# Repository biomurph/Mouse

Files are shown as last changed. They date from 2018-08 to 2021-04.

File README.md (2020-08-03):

# Mouse
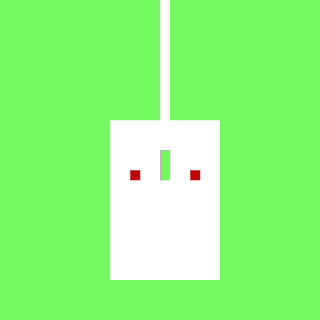
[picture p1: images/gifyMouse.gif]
MouseyMouse


### Repository for Open Source Mouse Firmware and Hardware
This repository holds the Arduino library, KiCAD PCB design files, gerber production files, BOM, and assembly instructions for the open-source computer mouse goodie bag item from the 2018 OSHWA Summit. The circuit design, PCB layout, and code were produced by Joel Murphy (aka biomurph | @SafeForRobots) in the Summer of 2018. The mouse wheel and wheel holder were designed in collaboration with Eugene Chang, and manufactured by [Tangible Creative](https://www.tangiblecreative.com). The production PCB boards were fabricated and stuffed by [Worthington Assembly](https://www.worthingtonassembly.com/). Thanks to Kelly Saxton for help in kitting and assembly instructions and the killer mouse morph gif! The microcontroller on board is a ATmega32u4 with Arduino Leonardo bootloader. This open-source mouse is a soldering kit, and comes pre-programmed with the example sketch from the Mousey Arduino library.

#### Assembly Instructions [Here](https://github.com/biomurph/Mouse/blob/master/AssemblyInstructions.md)
#### Library Functionality [Here](https://github.com/biomurph/Mouse/blob/master/LibraryFunctionality.md)
#### Hardware Design Files [Here](https://github.com/biomurph/Mouse/tree/master/Hardware)

## Anatomy of Mouse
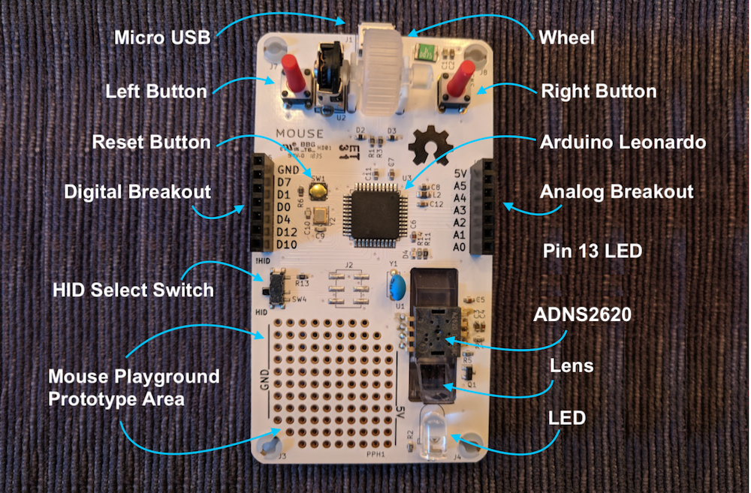
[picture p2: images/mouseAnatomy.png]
mouseProduction

### ADNS2620 !? That Went EOL Years Ago!
Yes, yes it did. Years ago, I tried to make a go of it in open-source hardware design, production and sales. I made something like [this](https://www.sparkfun.com/products/retired/10105) before SparkFun did, but it never got off the ground. I've been sitting on a small pile of components from those days, and this summer I decided that I have to chip away at that pile. So here you go. A fully functional computer mouse for you to hack and modify to your hearts delight. You're welcome!

If you are interested in modifying the design files to bring this project up to date, the one place that I have found that still sells these kinds of optical mouse sensors is a company called [PixArt](http://www.pixart.com.tw/index.asp) that has a variety of sensors to choose from. One of my goals is to do just that, so watch this repo if you want to be among the first to know when I have a working prototype.

### Installing The Firmware
Either download the ZIP of this repo or clone it. Then move or copy the file named `Mousey`
into your `Documents > Arduino > libraries` folder. Open or restart Arduino, Then
goto `File > Examples > Mousey > OpenMouse` to find the sketch that runs on OpenMouse.

# Use Your Mouse
This open-source computer mouse is built around an ATmega32u4 with the Arduino Leonardo bootloader. It has already been programmed with the example sketch from the Mousey library. There are two modes of operation HID and Not-HID. Modes are selected using the slide switch on the left side of the mouse.

## HID Mode
When the slide switch is on the side closest to the pad per hole prototyping area (aka DOWN), the mouse is in HID mode. When plugged into a micro USB cable, the mouse will read the sensors (wheel, buttons, optical sensor), and function just like a mouse attached to your computer!

## Not-HID Mode
When the slide switch is on the side closest to the 7 pin female header (aka UP), the mouse is in the Not-HID mode. When plugged into a micro USB cable, the mouse will read the sensors (wheel, buttons, optical sensor) and send the data it gets over serial at 115200 baud. You can open any serial terminal to view the data from the mouse.

## Troubleshooting
The mice were packaged with the HID select switch in the HID position. If you plug your mouse in to a computer and it doesn't work like a mouse should, then check to make sure that the HID switch is in HID mode. The small tact switch labeled `SW1` is the reset button for the Leonardo. You can switch modes on the fly, and press this reset button to change modes without unplugging your mouse. If all else fails, re-program the mouse with the OpenMouse.ino code from the example in the Mousey Library.

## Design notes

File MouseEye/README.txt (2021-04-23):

This Read Me is for Rachel's Electronics Mouse Eye Library. 
Written by Joel Murphy, Fall 2010
This Library offers full access to all the functionality 
of the Avago ADNS2620 at the heart of the Mouse Eye.
Use of the Library is discribed here.

First, connect the SDIO and SCK lines from the Mouse Eye to the arduino.
Any digital pins (2...13) will work for this connection.

To creat an instance of the Mouse Eye:
	MouseEye yourName(int SCK, ing SDIO);

This library sets up 2 variables and updates them through user functions. 

	.deltaX	char	holds change in X since the last time you ran .getMouse()
	.deltaY	char	holds change in Y since the last time you ran .getMouse()

>>>>>>   USER FUNCTIONS   <<<<<<<

	yourName.getMouse();

This function updates the variables .deltaX and .deltaY when you call it.
Variables will hold the change since the last time you called .getMouse().
Calling .getMouse() clears the X and Y registers.
Movement distance result is encoded as a 2's compliment number. The char type resolves this.

	yourName.Cofig_W(byte);

Writes a byte to the configuration register. Configuration register bits are:

	bit 7	Reset		0: no effect	1: reset the part
	bit 6	Power Down	0: normal operation	1: power down
	bit 5	Shutter Mode	0: Shutter Mode Off	1: Shutter Mode On
	bit 4...1	RESERVED
	bit 0	Forced Awake	0: Normal		1: Always Awake

Shutter Mode Off means the LED is always on even if no movement up to 1 second
Shutter Mode On means LED only on when electronic shutter is open

	byte yourName.Config_R();

Reads and returns the Configuration byte.

	byte yourName.Status();

Returns a byte that contains the product ID and mouse state data

	bits 7...5 		= Product ID  (010)
	bit 1		= Asleep/Awake  (0/1)

	byte yourName.Squal();

Returns a byte that reflects the surface quality of what the Mouse Eye sees.
This number x2 is the number of visible features on the surface. 
It is useful to read this register if you are finding the ideal distance between you mouse and the surface it is looking at.

	byte = yourName.Max_P();

Maximum gray scale value of a pixel in the current frame. Range = 0 to 63.

	byte = yourName.Min_P();

Minimum gray scale value of a pixel in the current frame. Range = 0 to 63.

	byte = yourName.Pixel_Sum();

Returns the average pixel gray scale value. Range from 0 to 63.

	word = yourName.Shutter();

Length of time the shutter is open in clock cycles. The sensor adjusts shutter to keep average and maximum pixel values within normal operating range. Value may change. Each time it changes, it changes by +- 1/16 of current value.

	void yourName.F_Period_W(byte);

Writes a byte to the Frame_Period register. Default value is 194. For dark surfaces, use a lower number.
see the datasheet for more details [http://www.rachelselectronics.com/Datasheets/ADNS-2620.pdf]

	byte yourName.F_Period_R();

Reads the value in the Frame_Period Register.

	your name.Pixel_Data_R();

Writes a byte to the Pixel_Data register to initiate frame capture and pixel dump. 
This command should be preceeded by a write of 1 to the Config register set the mouse in Awake mode.
Then there should be 324 successive reads from this register using yourName.Pixel_Data_R().
Here is an example use of the Pixel_Data commands:

	MoueseEye Mouse(int SCK, int SDIO);	// create instance of MouseEye

	byte P_data [324];			// byte array to hold grayscale data

	void setup(){
	Serial.begin (9600);
	}

	void loop(){
		//some event triggers a call to dumpPixels();
	}

	void dumpPixels(){
	    Mouse.Config_W(1);             	// force awake
	    Mouse.Pixel_Data();		// writes a byte to initiate pixel dump
	    for (int i=0; i<324; i++){
	      P_data[i] = Mouse.Pixel_Data_R();	//read grayscale data
	    }  
	    for (int i=0; i<324; i++){
	      Serial.print(P_data[i]); 		// display grayscale data
	    }
	    Mouse.Config_W(0);              	// undo force awake
	  }

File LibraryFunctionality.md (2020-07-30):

# Mouse Library Tools
Here is information about the user accessible functions in the Mousey library. The format of the data that is sent to the computer is determined by the HID select switch on the PCB. When the switch is set to `!HID` the mouse will send ASCII data to a serial terminal at 115200 baud whenever a mouse event occurs. When the switch is set to `HID` the mouse will use `Mouse.move`, `Mouse.pressed`, and `Mouse.released` to send mouse event data to the computer.

## update()
update checks all of the mouse inputs and sends relevant data to the computer if the buttons are pressed or released, if the mouse wheel moves, or if the mouse itself moves. It has proved to be important to have a delay in the loop when using the Mousey library, or else the mouse will overload the computer HID receiver and it will reduce performance. Experiment has shown that a delay of 5-10 milliseconds is good enough.

## checkEye()
Performs the necessary functions to update the `deltaX` and `deltaY` variables if they have changed, and sets the `mouseMoved` variable if that is so.

## checkWheel()
Checks to see if the `checkWheel` flag has been set by the interrupt service routine and sets the `mouseMoved` variable if that is so. The variable `deltaWheel` will hold the most recent wheel move data.

## checkButtons()
Reads the mouse buttons with a timed debounce routine and if there is a change in any of the button states, it sends data to the computer.

## Wheel Encoder
The mouse wheel encoder is of the digital switch type. There is an interrupt service routine called `encode()` which is triggered any time one of the encoder pins change state. The function `checkWheel()` will set the variable `wheelMoved` to true if the mouse wheel has moved, and the variable `deltaWheel` will contain the movement data.

## ADNS2620 Functions
The ADNS2620 Optical Mouse Sensor is at the heart of this open source computer mouse project. The Mousey library contains user accessible functions to access it's power. Here's a list of those functions and what they do. A copy of the ADNS2620 Datasheet can be found in the Hardware folder of this repository.

**NOTE: The ADNS2620 has gone EOL and is no longer available. I am looking into ICs from [PixArt](http://www.pixart.com.tw/index.asp) and will update this repository with a suitable replacement sensor soon.**

### getMouseEyeDelta()
This function updates the variables `deltaX` and `deltaY` with the latest relative movement data in 8 bit 2's compliment format.

### byte Config_Read()
Returns the value of the Configuration register.

### Config_Write(byte)
Writes a byte to the Configuration register.

### byte Status()
returns the value of the Status register. Status register contains the part ID and the Awake bit.

### int Squal()
Returns the value of the Squal register. Squal holds the Surface Quality value, which is a measure of the number of features visible by the sensor. The range is from 0 to 510.

### byte Max_Pixel()
Returns the maximum pixel value in the frame. The range is from 0 to 63.

### byte Min_Pixel()
Returns the minimum pixel value in the frame. The range is from 0 to 63.

### int Pixel_Sum();
Read this register is used to find the average pixel value. Refer to the datasheet inside the Hardware folder for more information about this register.

### word Shutter();
Returns the duration of the shutter open time in clock cycles. Refer to the datasheet inside the Hardware folder for information on how to derive the frame rate.

### short Frame_Period_Read();
### Frame_Period_Write(short);
These functions can be used to optimize performance when the mouse is over dark surfaces. RTDS.

### void Pixel_Data();
Any writes to this register will set the ADNS pointer so that the next read will return the value of the first pixel in the frame. Use Pixel_Data_Read to get pixel data.

### byte Pixel_Data_Read();
After writing to Pixel_Data, use this function to read the values of the individual pixels in a frame. Values range from 0 to 63. There are 324 pixels in the frame.

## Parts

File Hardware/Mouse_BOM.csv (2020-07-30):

Id | Designator | Package | Quantity | Designation | Manufacturer | Part Number | URL
2 | C1 | C_0603 | 1 | 10uF | Murata | GRM188R60J106KE47D
3 | C2,C4,C6,C7,C12 | C_0603 | 5 | 0.1uF | Yaego | CC0603ZRY5V7BB104
4 | C3 | C_0603 | 1 | 4.7uF | Taiyo | JMK107C6475MA-T
5 | C5 | C_0603 | 1 | 2.2uF | Yaego | CC0603ZRY5V6BB225
6 | C8,C11 | C_0603 | 2 | 1uF | Kemet | C0603C105Z9VACTU
7 | C9,C10 | C_0603 | 2 | 18pF | Kemet | C0603C180K5HACAUTO
8 | D2,D3 | C_0603 | 2 | TVS Diodes | Bourns | CG0603MLC-05E | https://www.mouser.com/ProductDetail/Bourns/CG0603MLC-05E?qs=lDok7oSghXVLNKMK69q%252bFQ%3D%3D
9 | F1 | C_1812 | 1 | FUSE | Bourns | MF-MSMF050-2 | https://www.mouser.com/ProductDetail/Bourns/MF-MSMF050-2
10 | J1 | 10118193_microUSB | 1 | USB_OTG | Amphenol | 10118193-0001LF | https://www.mouser.com/ProductDetail/Amphenol-FCI/10118193-0001LF
11 | J2 | Pin_Header_Straight_2x03_Pitch2.54mm_SMD | 1 | CONN_02X03 | DNP | DNP
12 | L1,L2 | C_0805 | 2 | 300ohm Ferrite Bead | Laird | LI0805G301R-10 | https://www.mouser.com/ProductDetail/Laird/LI0805G301R-10?qs=sGAEpiMZZMtdyQheitOmRXJdVJiWCa9XidKUz3Eoh40%3d
13 | Q1 | SOT-23 | 1 | PNP Transistor | ON Semi | BC857ALT1G | https://www.mouser.com/ProductDetail/ON-Semiconductor/BC857ALT1G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
14 | R1,R3 | C_0603 | 2 | 22R | Bourns | CR0603-JW-220ELF
15 | R2 | C_0603 | 1 | 33R | Panasonic | ERJ-3GEYJ330V
16 | R4 | C_0603 | 1 | 100K | Panasonic | ERJ-3GEYJ104V
17 | R5,R14 | C_0603 | 2 | 1K | Panasonic | ERJ-3GEYJ102V
18 | R6,R11,R13 | C_0603 | 3 | 10K | Stackpole | RNCP0603FTD10K0
19 | SW1 | PTS540_Switch | 1 | Tact Switch | C&K | PTS540JM035SMTRLFS | https://www.mouser.com/ProductDetail/CK/PTS540JM035SMTRLFS
20 | Y2 | Crystal_SMD_3225-4pin_3.2x2.5mm | 1 | 16MHz Xtal | Murata | XRCGB16M000FXN1R0 | https://www.mouser.com/ProductDetail/Murata-Electronics/XRCGB16M000FXN1R0
21 | Y1 | C_Disc_D5.0mm_W2.5mm_P5.00mm | 1 | 24MHz | DNP | DNP
22 | D4 | C_0603 | 1 | Red LED | ROHM | SML-D12U1WT86 | https://www.mouser.com/ProductDetail/ROHM-Semiconductor/SML-D12U1WT86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
23 | SW4 | SSSS810701_ALPS | 1 | SPDT Slide Switch | Alps | SSSS810701 | https://www.mouser.com/ProductDetail/ALPS/SSSS810701
24 | U3 | LQFP-44_10x10mm_Pitch0.8mm | 1 | ATMEGA32U4-MU | Microchip | ATMEGA32U4-AU | https://www.mouser.com/ProductDetail/Microchip-Technology-Atmel/ATMEGA32U4-AU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
25 | D1 | LED_D5.0mm_Horizontal_O1.27mm_Z3.0mm | 1 | 5mm LED | DNP | DNP
26 | U2 | Mouse_Encoder | 1 | ENCODER-QUADRATURE | Cloukeu | 9mm Mouse Encoder | https://www.aliexpress.com/item/10Pcs-5MM-7MM-9MM-11MM-13MM-Mouse-encoder-11mm-wheel-decoder/32457386770.html
27 | SW2,SW3 | LL3301DF065QJ | 2 | Push Button Switch | E-Switch | LL3301DF065QJ | https://www.mouser.com/ProductDetail/E-Switch/LL3301DF065QJ
29 | J5,J6 | Pin_Header_Straight_1x07_Pitch2.54mm | 2 | CONN_01X07 | Preci-Dip | 801-87-007-10-001101 | https://www.mouser.com/ProductDetail/Preci-dip/801-87-007-10-001101
30 | U1 | ADNS2610 | 1 | ADNS2610PTH | DNP | DNP

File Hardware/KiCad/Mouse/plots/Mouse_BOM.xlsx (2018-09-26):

 | MOUSE BOM
Id | Designator | Package | Quantity | Designation | Manufacturer | Part Number | Notes
1 | C1 | C_0603 | 1 | 10uF | Murata | GRM188R60J106KE47D
2 | C2,C4,C6,C7,C12 | C_0603 | 5 | 0.1uF | Yaego | CC0603ZRY5V7BB104
3 | C3 | C_0603 | 1 | 4.7uF | Taiyo | JMK107C6475MA-T
4 | C5 | C_0603 | 1 | 2.2uF | Yaego | CC0603ZRY5V6BB225
5 | C8,C11 | C_0603 | 2 | 1uF | Kemet | C0603C105Z9VACTU
6 | C9,C10 | C_0603 | 2 | 18pF | Kemet | C0603C180K5HACAUTO
7 | D1 | LED_D5.0mm_Horizontal_O1.27mm_Z3.0mm | 1 | RED LED 630nm | Cree | C503B-RAN-CZ0C0AA1 | DNP
8 | D2,D3 | C_0603 | 2 | TVS Varistor | Bourns | CG0603MLA-5.5ME
9 | D4 | C_0603 | 1 | LED | Wurth | 150060BS75000
10 | F1 | C_1812 | 1 | Fuse | Bel Fuse | 0ZCG0075FF2C
11 | J1 | 10118193_microUSB | 1 | USB_OTG | Amphenol | 10118193-0001LF
12 | J2 | Pin_Header_Straight_2x03_Pitch2.54mm_SMD | 1 | CONN_02X03 | DNP | DNP | DNP
13 | J5,J6 | Pin_Header_Straight_1x07_Pitch2.54mm | 2 | CONN_01X07 | Sullins | PPTC071LFBN-RC | DNP
14 | L1,L2 | C_0805 | 2 | Ferrite Bead | Bourns | MU2029-301Y
15 | Q1 | SOT-23 | 1 | PNP BEC | ON Semi | BC857ALT1G
16 | R1,R3 | C_0603 | 2 | 22R | Bourns | CR0603-JW-220ELF
17 | R2 | C_0603 | 1 | 33R | Panasonic | ERJ-3GEYJ330V
18 | R4 | C_0603 | 1 | 100K | Panasonic | ERJ-3GEYJ104V
19 | R5,R14 | C_0603 | 2 | 1K | Panasonic | ERJ-3GEYJ102V
20 | R6,R11,R13 | C_0603 | 3 | 10K | Stackpole | RNCP0603FTD10K0
21 | SW1 | PTS540_Switch | 1 | PTS540 JM035 SMTR LFS | C&K | PTS540JM035SMTRLFS
22 | SW2,SW3 | Push Button | 2 | SPST | E-Switch | TL1105DF250Q | DNP
23 | SW4 | SSSS810701_ALPS_DPDT | 1 | SPDT | Alps | SSSS810701
24 | U1 | ADNS2610 | 1 | Optical Sensor | Avago | ADNS2610PTH | DNP
25 | U2 | Mouse_Encoder | 1 | ENCODER-QUADRATURE | Cloukeu | Mouse Encoder 9mm | DNP | https://www.aliexpress.com/item/10Pcs-5MM-7MM-9MM-11MM-13MM-Mouse-encoder-11mm-wheel-decoder/32457386770.html
26 | U3 | LQFP-44_10x10mm_Pitch0.8mm | 1 | ATMEGA32U4-MU | Microchip | ATMEGA32U4RC-AU
27 | Y1 | C_Disc_D5.0mm_W2.5mm_P5.00mm | 1 | 24MHz Resonator | TDK | FCR24.0M6T | DNP
28 | Y2 | Crystal_SMD_3225-4pin_3.2x2.5mm | 1 | 16 MHz Crystal | Epson | FA-238 16.0000MB-C3

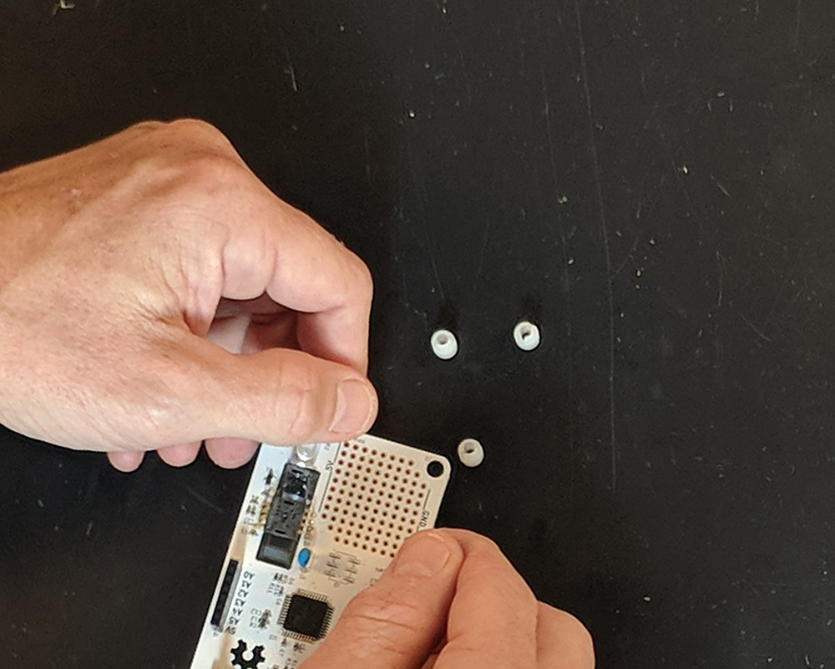
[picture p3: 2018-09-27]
images/MouseParts-_0020_32.jpg

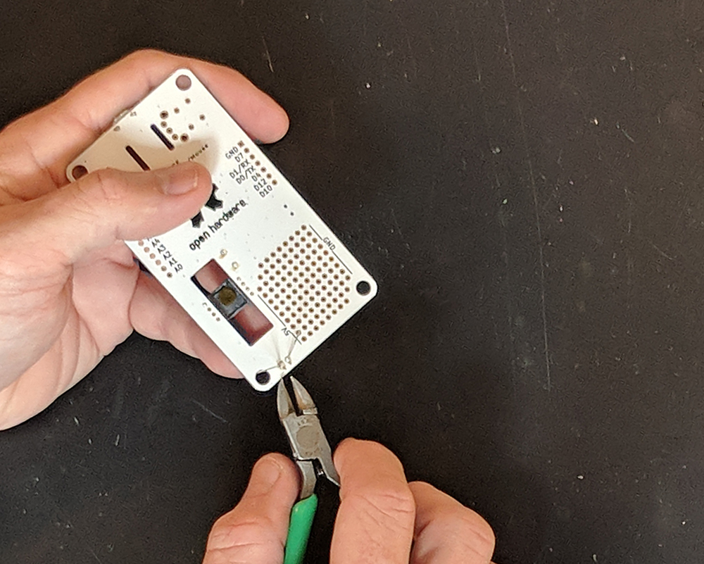
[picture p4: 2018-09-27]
images/MouseParts-_0000_14.jpg

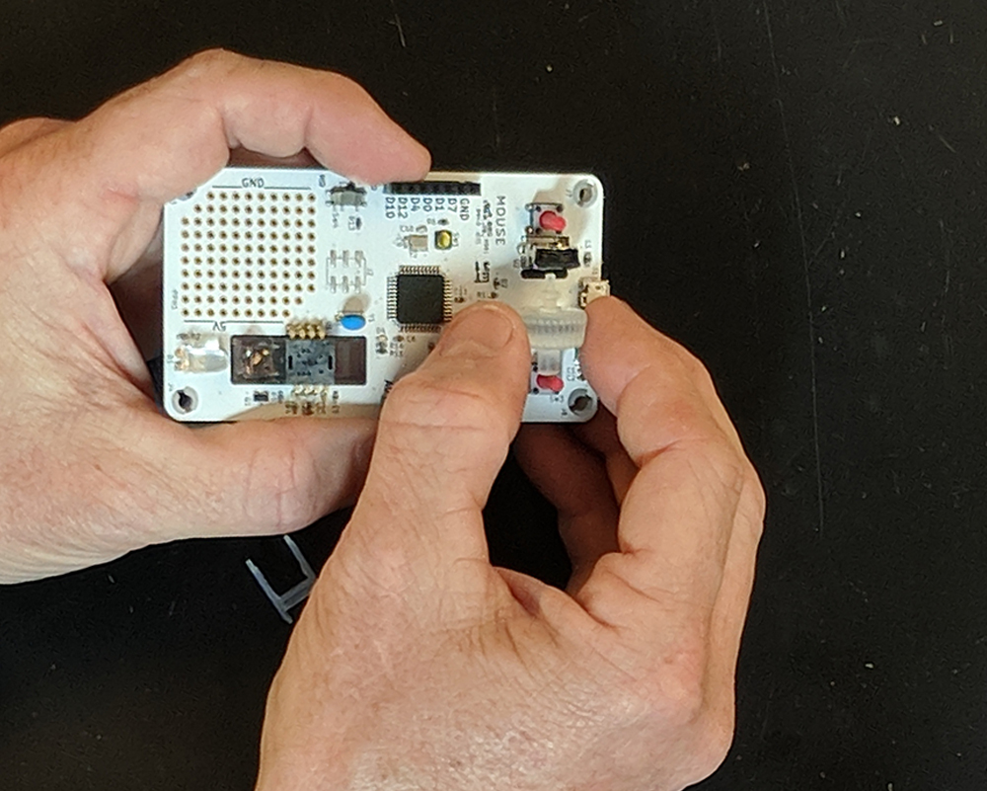
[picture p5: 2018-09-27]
images/MouseParts-_0016_36.jpg

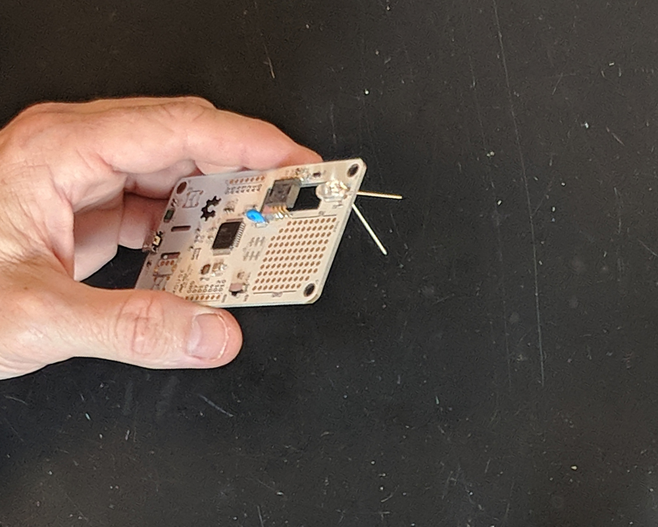
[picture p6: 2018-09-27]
images/MouseParts-_0002_12.jpg

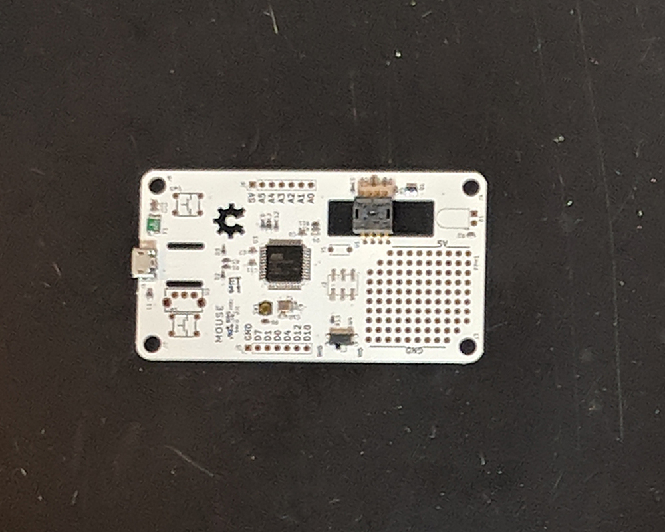
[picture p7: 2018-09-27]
images/MouseParts-_0009_04.jpg

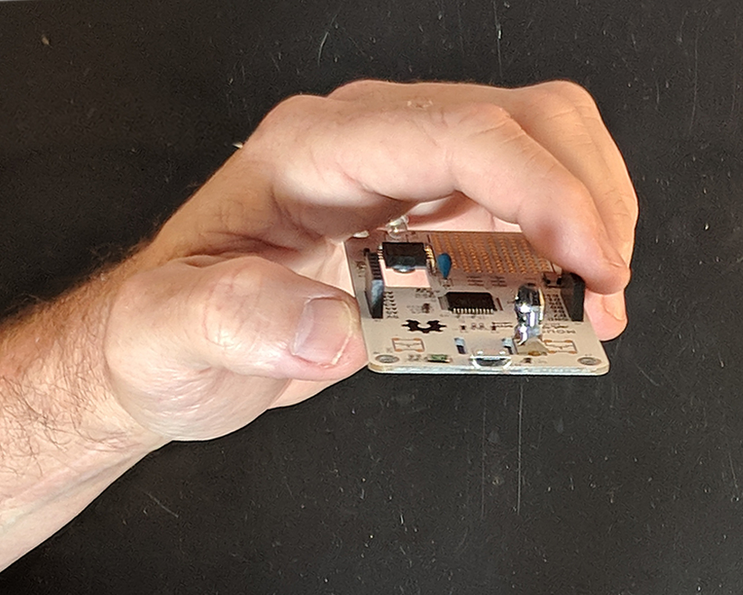
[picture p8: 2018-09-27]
images/MouseParts-_0030_17.jpg

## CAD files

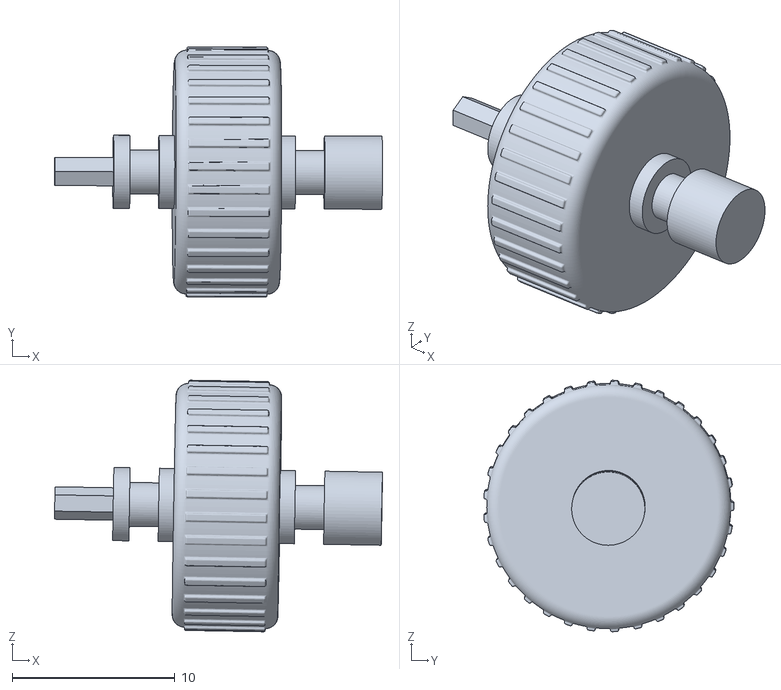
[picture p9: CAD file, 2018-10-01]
Hardware/Wheel/Assem6 - Mouse_Wheel.STL
20.2 x 15.4 x 15.5

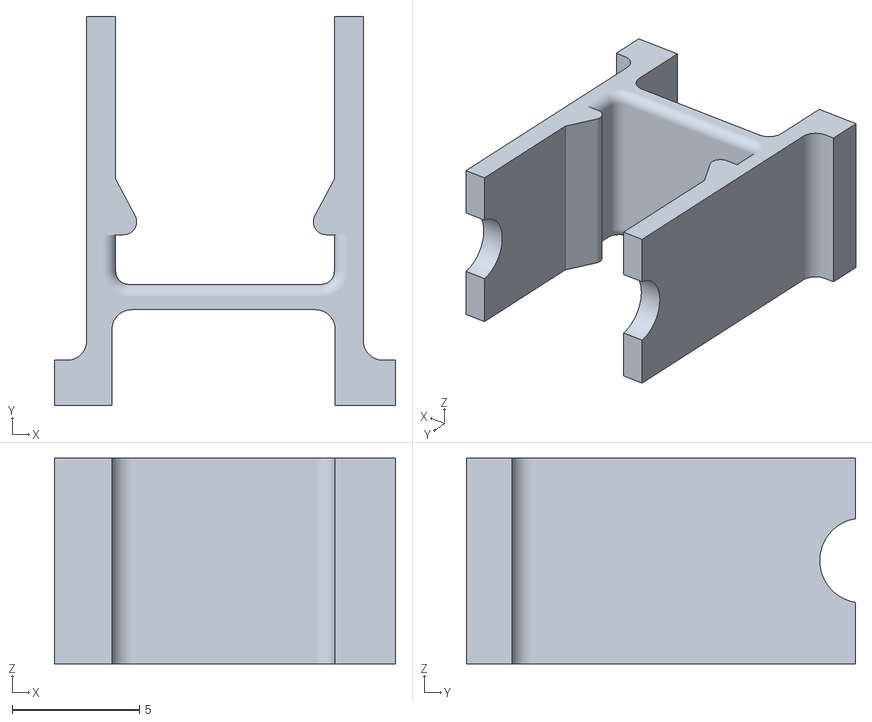
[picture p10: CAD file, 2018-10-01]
Hardware/Wheel/Clip^Assem9.STL
13.4 x 15.3 x 8.08

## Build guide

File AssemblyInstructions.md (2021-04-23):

# Mouse Assembly Instructions

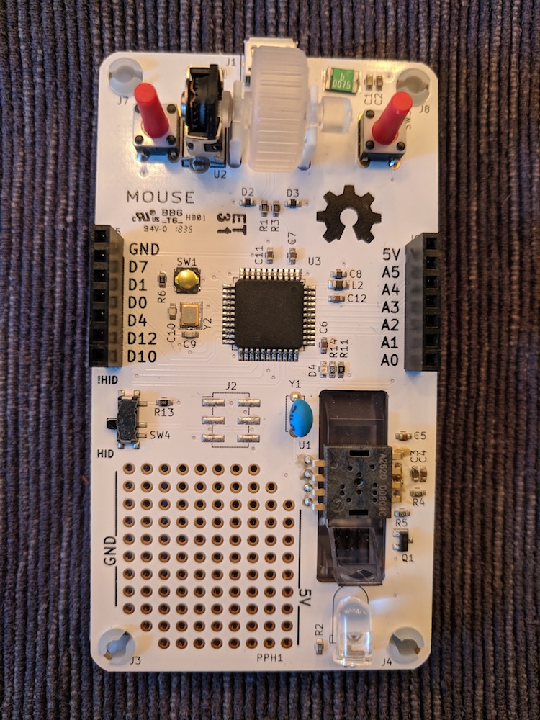
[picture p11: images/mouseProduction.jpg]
CompleteMouse


## What's in the Kit

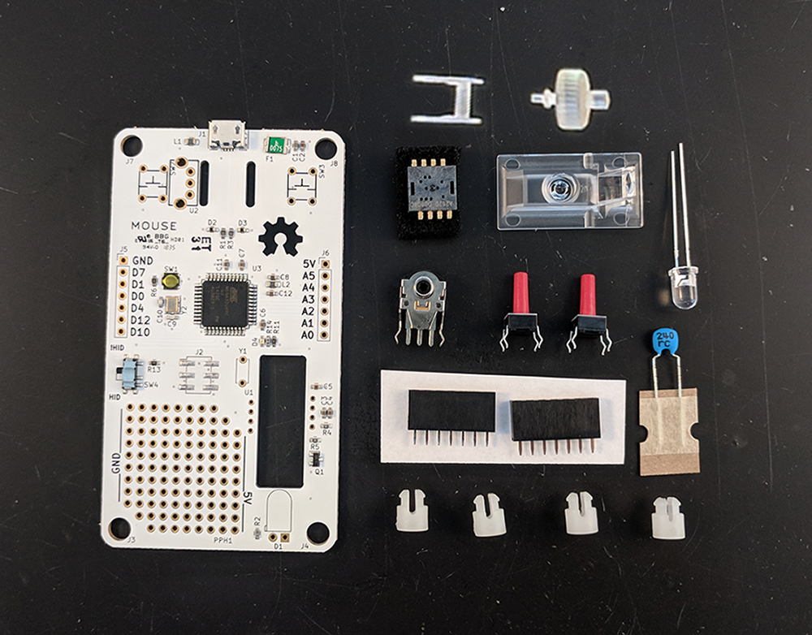
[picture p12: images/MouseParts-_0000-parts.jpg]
KitContents


* 1 PCB populated with SMT components
* 1 ADNS2620 Optical Mouse sensor
* 1 Clear plastic lens for ADNS sensor
* 1 Mouse Wheel encoder
* 2 Red pushbutton switches
* 2 7 pin female headers
* 1 24MHz resonator
* 4 plastic Feet
* 1 Mouse wheel
* 1 Mouse wheel holder

## Step One: ADNS2620 at U1
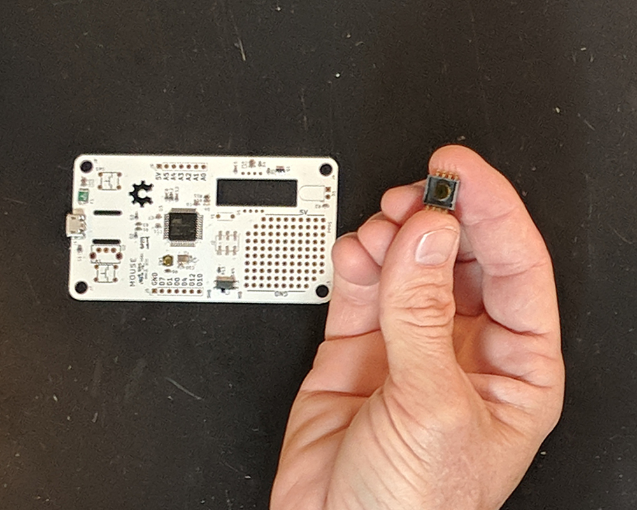
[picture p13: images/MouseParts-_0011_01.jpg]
ADNS_1

The ADNS2620 sensor has a small piece of kapton tape covering the lens. **Do Not** remove the kapton tape until directed to by these instructions. It will protect the lens from any random goo or dust getting in there.

Solder the ADNS2620 optical sensor. It is **VERY** important that this part gets soldered at the right height on the board! Incorrect vertical position of the ADNS will cause the mouse to fail!

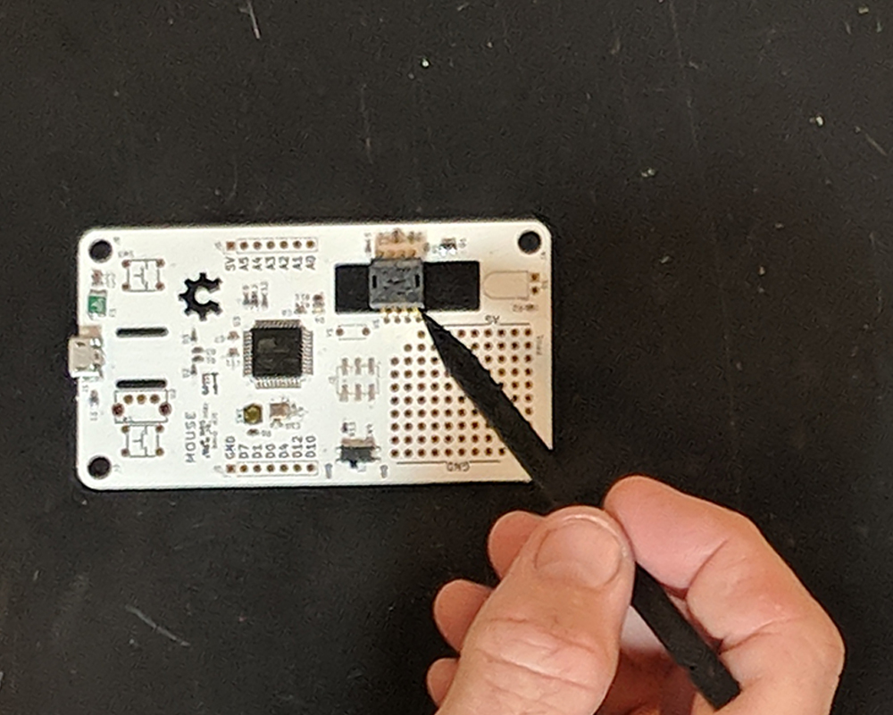
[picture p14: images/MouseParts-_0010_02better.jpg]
ADNS_2

Place the PCB flat side down on a smooth surface, and then put the ADNS legs into the PCB holes. Make sure that the ends of the ADNS legs are touching the surface of the table. The ADNS will be 'standing up' above the PCB. **NOTE THE ORIENTATION OF THE ADNS!** Pin 1 is marked by a small round circle in one corner of the IC, and Pin 4 is marked by the large round circle that I'm pointing to.

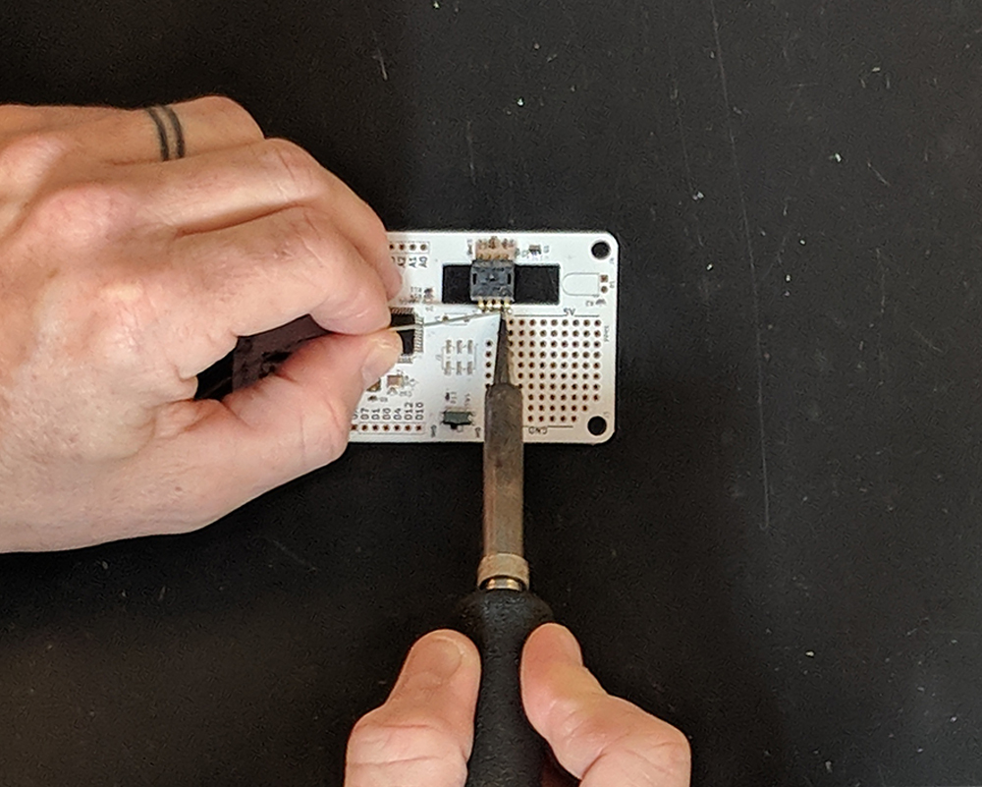
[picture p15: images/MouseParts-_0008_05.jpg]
ADNS_3

Once you have the part oriented correctly and the legs are touching the table top through the PCB holes with the PCB flat on the table top, go ahead and solder each leg from the top.

## Step Two: Resonator at Y1
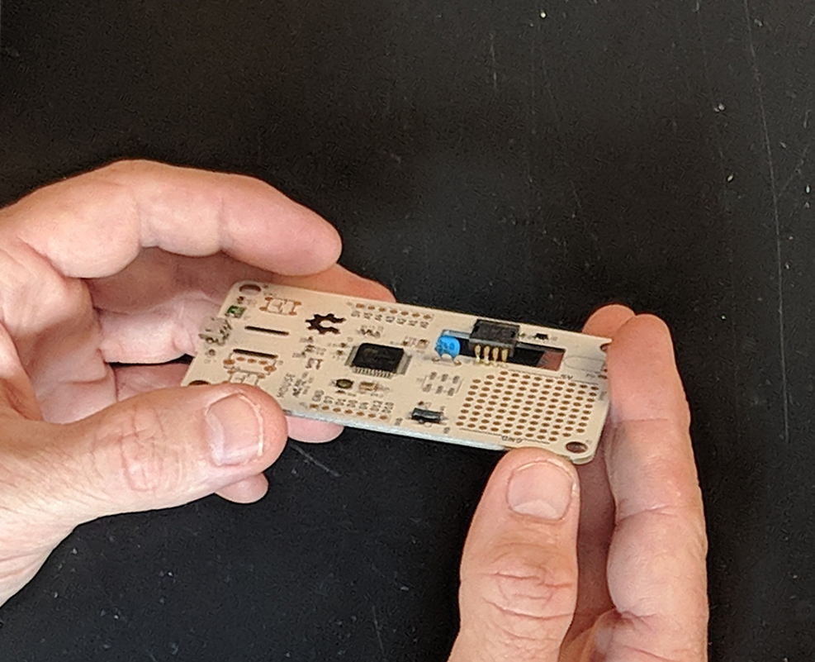
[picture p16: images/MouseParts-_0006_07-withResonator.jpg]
Resonator

The blue resonator fits in right next to the ADNS and it doesn't have any orientation. It can go either direction.

## Step Three: LED at D1
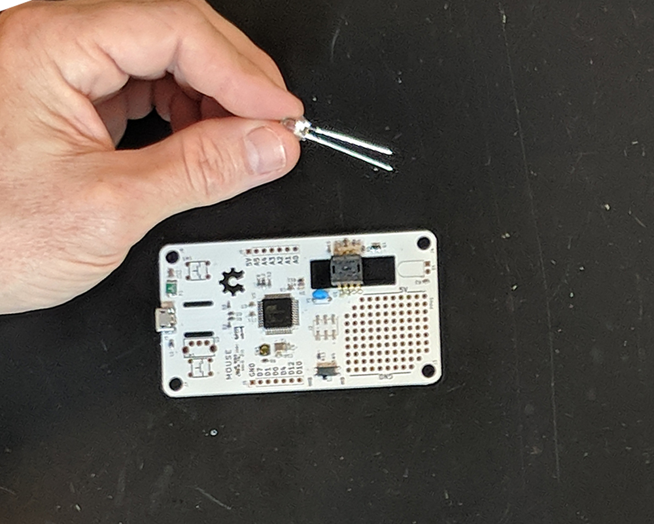
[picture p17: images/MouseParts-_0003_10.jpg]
LED_orient

The LED is oriented with the long leg toward the middle of the board.

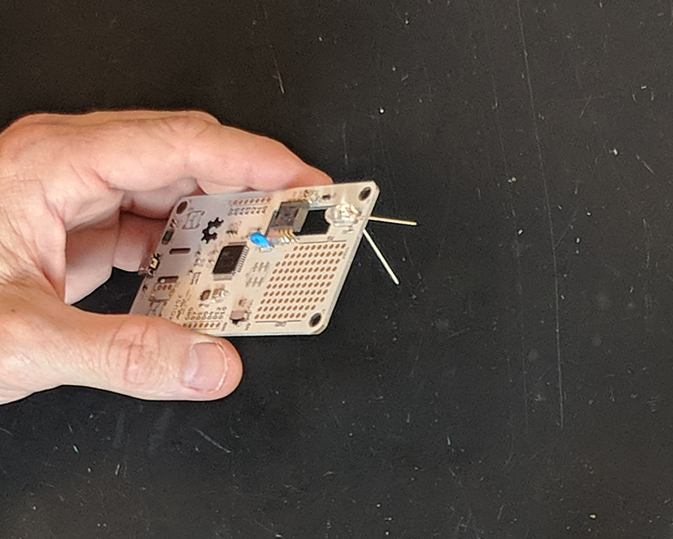
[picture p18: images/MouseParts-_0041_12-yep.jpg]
LED_bent

 The leads of the LED need to be bent at 90 degrees so that it will point toward the ADNS sensor.

## Step Four: Headers at J5 and J6
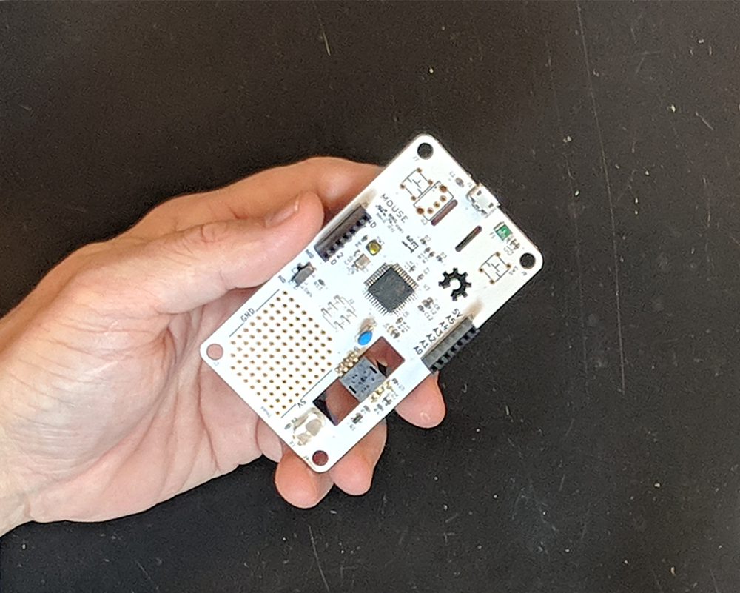
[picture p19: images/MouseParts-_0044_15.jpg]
Headers

Next, solder in the two 7 pin female headers. The PCB should sit flat on them upside down for easy soldering. Get one leg of each header soldered, and then turn over to board to make sure that the headers are sitting straight. Adjust as necessary by remelting the pin you soldered, then solder the rest of the pins.

## Step Five: Encoder at U2
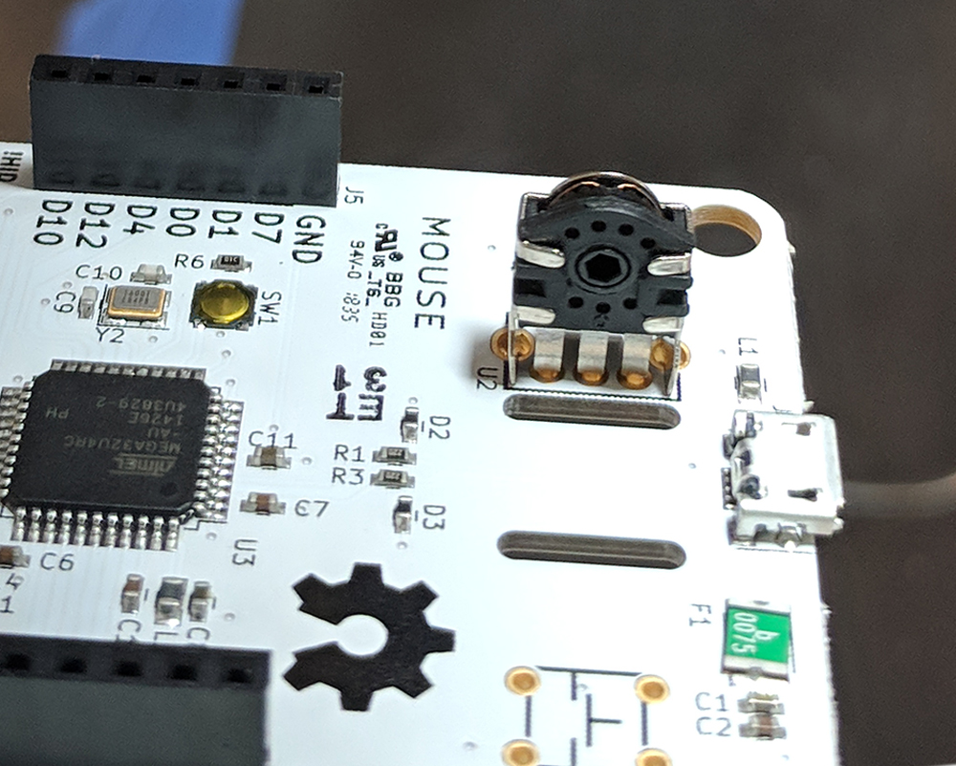
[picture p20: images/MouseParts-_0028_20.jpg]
Encoder_front

The encoder for the mouse wheel only goes in one way. There are two large clip leads on the sides. **Make sure that the encoder is inserted all the way** so that the base of the encoder sides is touching the top of the PCB.

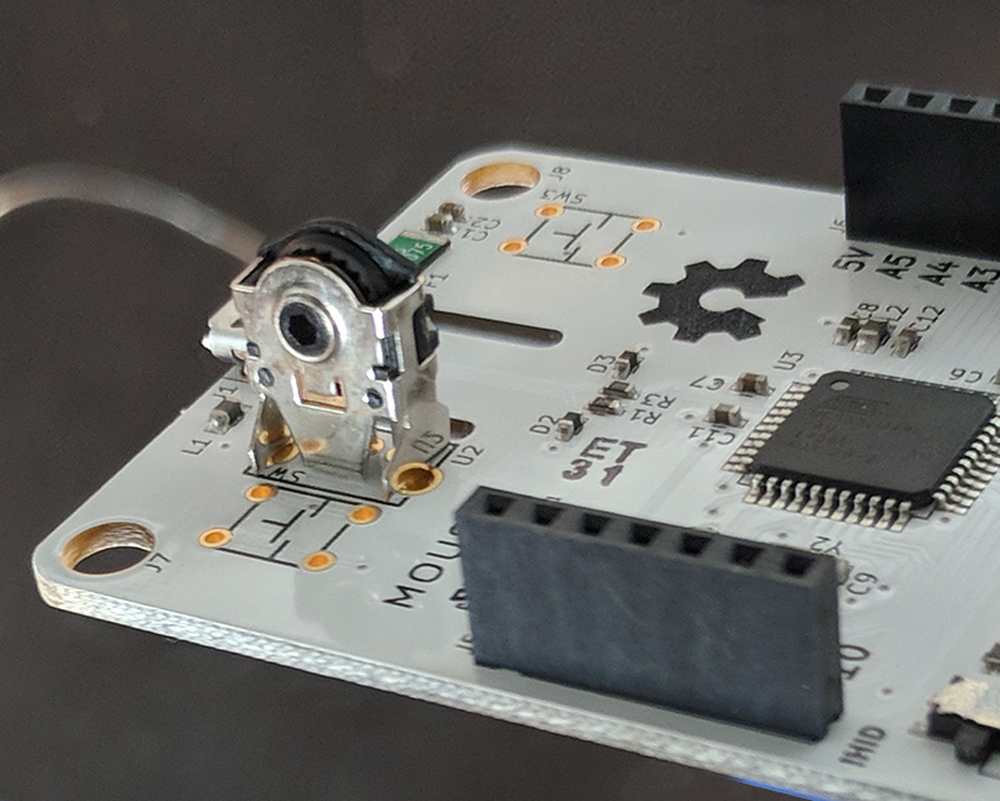
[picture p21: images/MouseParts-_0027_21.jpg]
Encoder_sideish

This will ensure that the wheel and wheel support will fit correctly later.

## Step Six: Buttons at SW2 and SW3
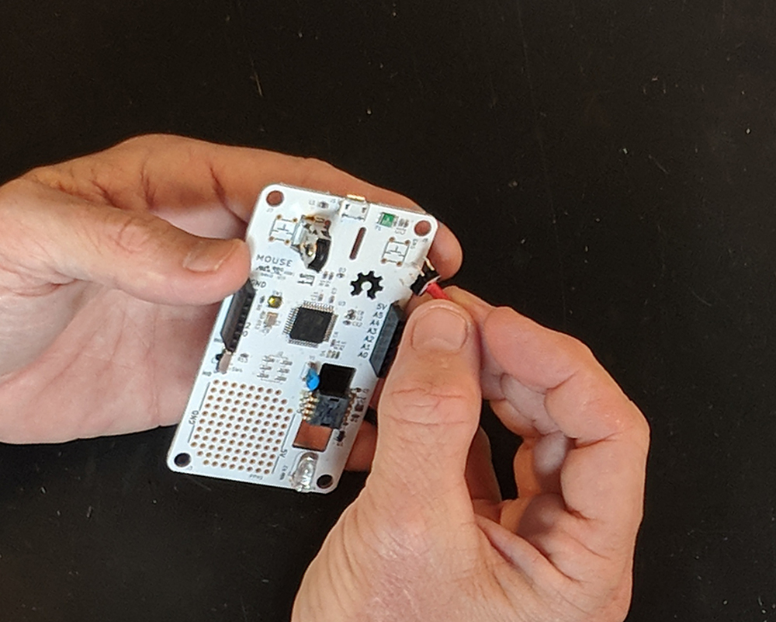
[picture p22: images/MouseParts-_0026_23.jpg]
Buttons

The two pushbutton switches only fit one way. The legs will snap into the PCB and hold them there for you to solder them.

## Step Seven: Lens
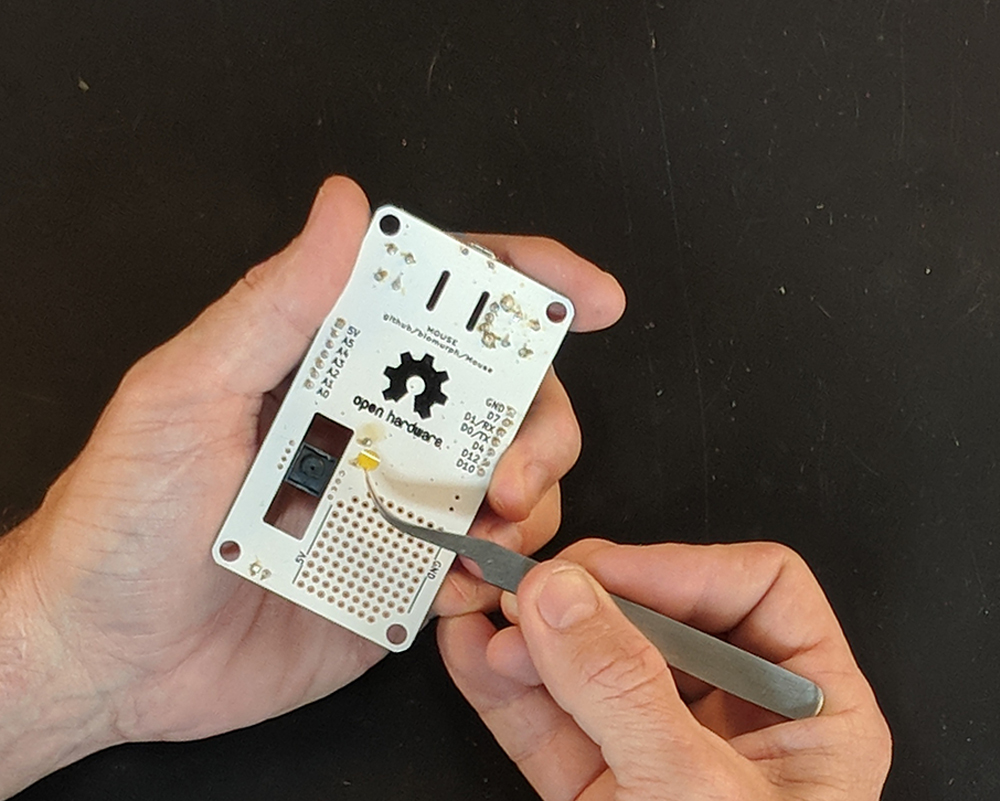
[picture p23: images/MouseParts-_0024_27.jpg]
Lens_1

Now it's time to attach the clear plastic lens to the bottom of the board. **FIRST REMOVE THE KAPTON TAPE**. Use a pair of tweezers or your fingernail to peel off the kapton tape that covers the ADNS lens.

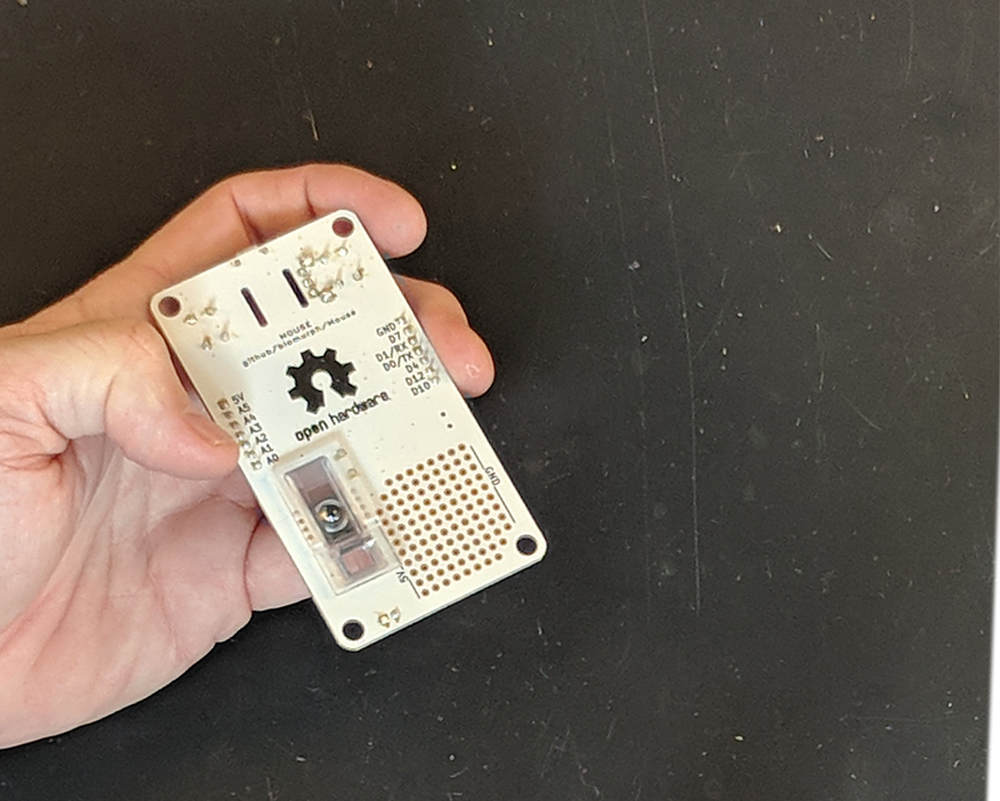
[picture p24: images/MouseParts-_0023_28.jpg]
Lens_2

Then, orient the lens so that the triangular prism is on the side with the LED.

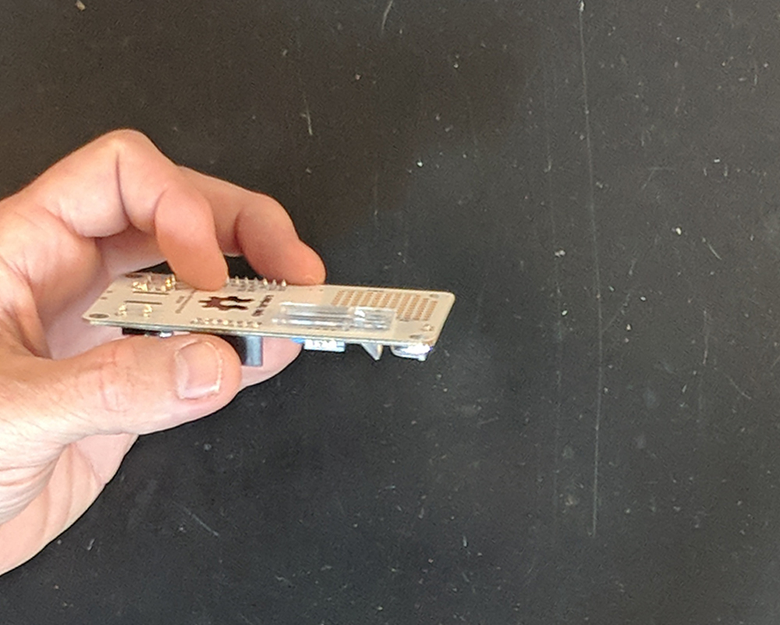
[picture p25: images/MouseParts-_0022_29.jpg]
Lens_3

The lens should fit flat against the ADNS lens.

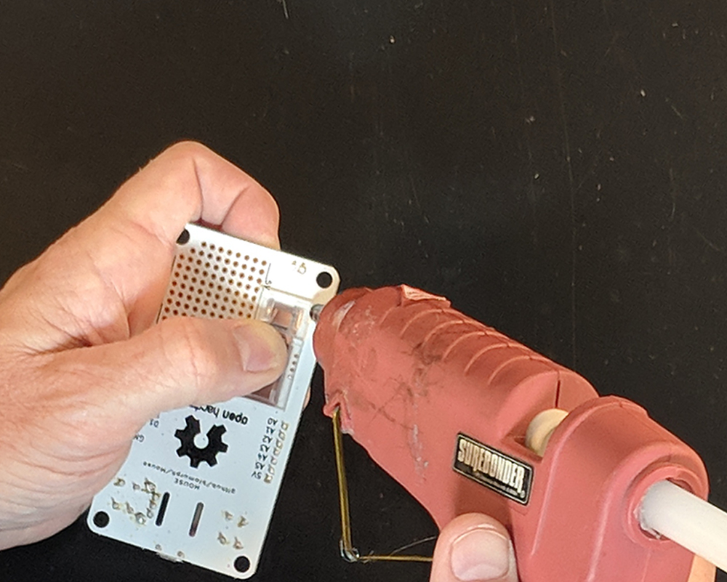
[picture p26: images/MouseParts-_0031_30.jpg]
HotGlue

I'm using hot glue to secure the lens to the bottom of the PCB. **DO NOT USE CYANOACRYLATE OR CRAZY GLUE IT WILL RUIN THE LENS!**

## Step Eight: Feet
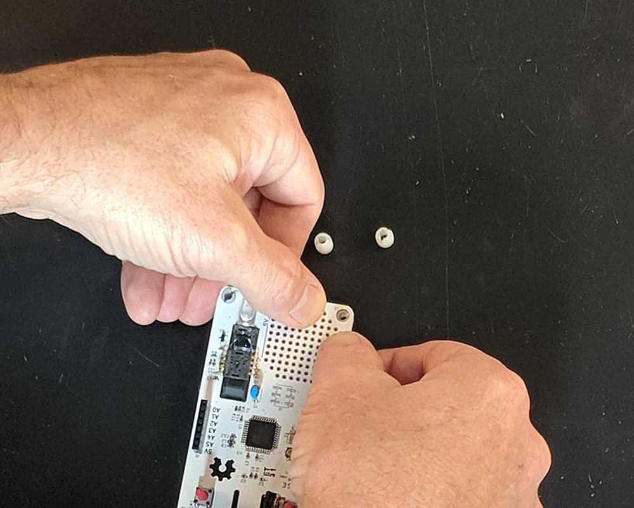
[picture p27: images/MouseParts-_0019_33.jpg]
Feet

Attach the feet to the PCB from the bottom. Place the feet upright on a table and press the PCB onto them until they snap into the holes.

## Step Nine: Wheel
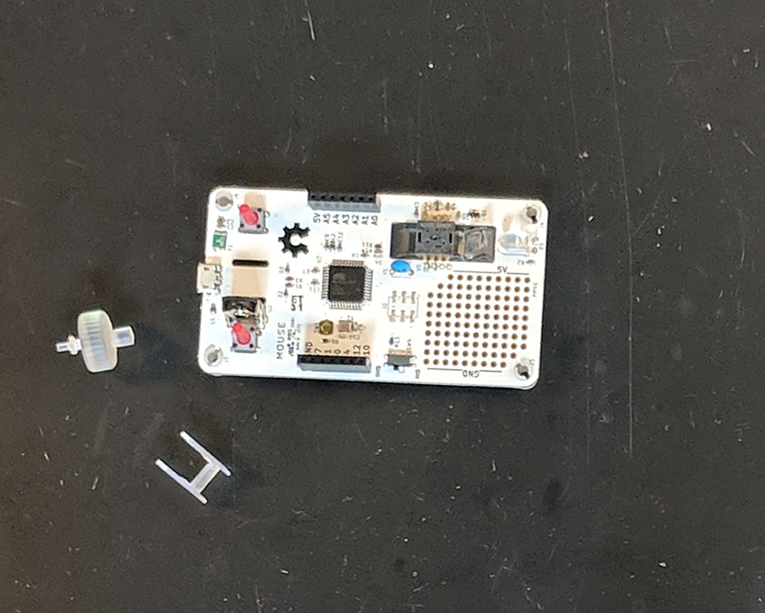
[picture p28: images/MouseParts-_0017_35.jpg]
Wheel_1

The clear mouse wheel has a small hex shaft on one end which fits perfectly into the hex hub of the encoder.

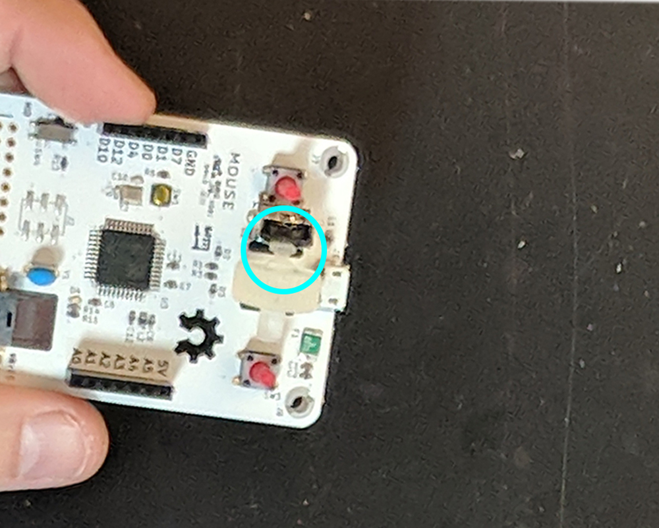
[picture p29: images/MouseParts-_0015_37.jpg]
Wheel_2

Slide the mouse wheel shaft into the encoder hub.

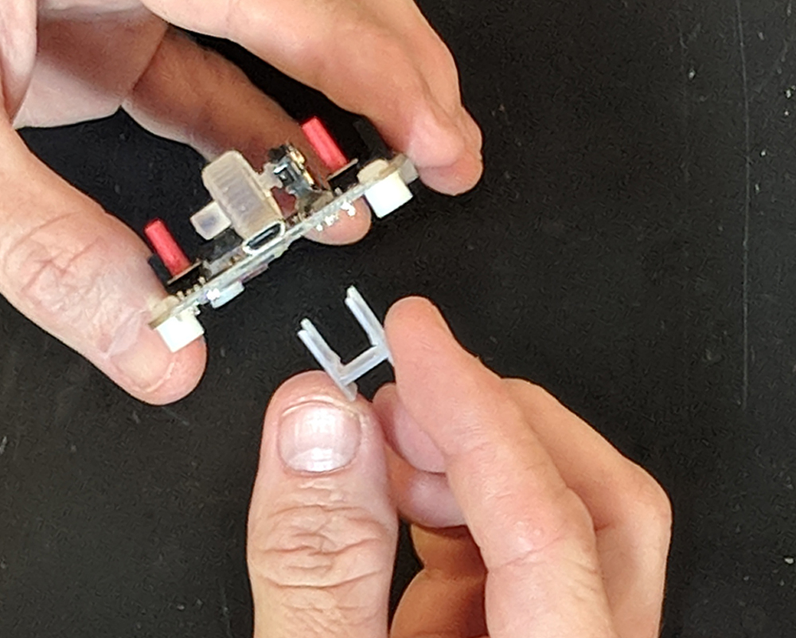
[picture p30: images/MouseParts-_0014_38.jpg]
Wheel_3

Then, insert the mouse wheel holder into the slots from the bottom of the PCB. ***be careful when doing this*** the parts have a snug fit, and if the cradle is not lined up with the wheel hub it might damage the wheel!

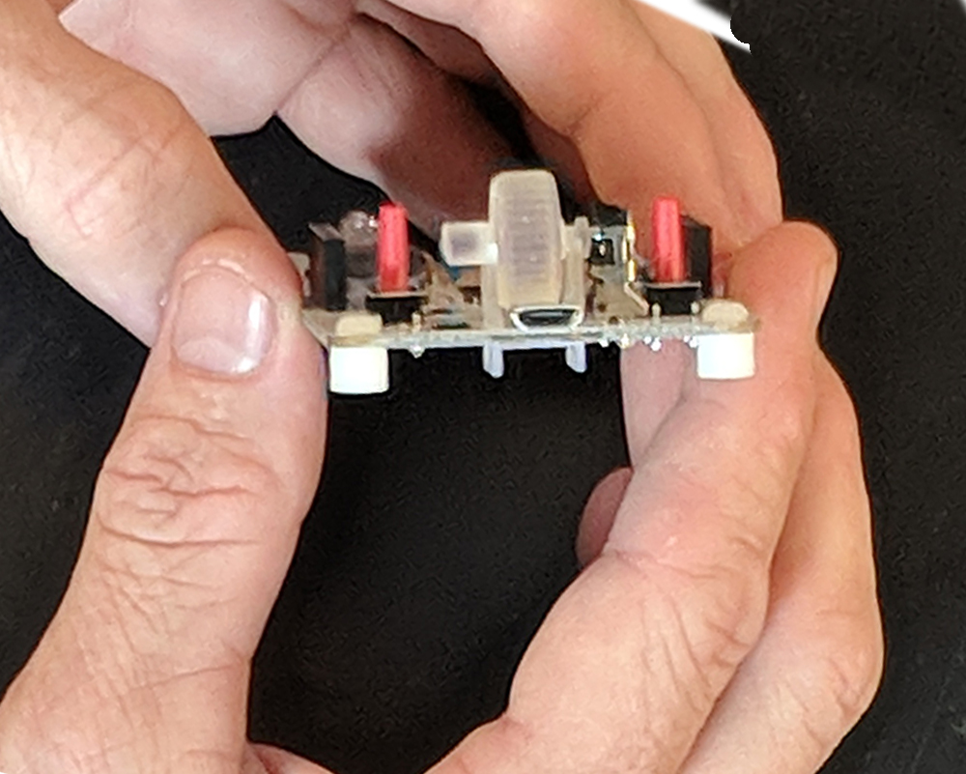
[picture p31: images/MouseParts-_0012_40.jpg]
Wheel_4

The holder will snap into place, and cradle the wheel axle on both sides.

# Use Your Mouse
This open-source computer mouse is built around an ATmega32u4 with the Arduino Leonardo bootloader. It has already been programmed with the example sketch from the Mousey library. There are two modes of operation HID and Not-HID. Modes are selected using the slide switch on the left side of the mouse.

## HID Mode
When the slide switch is on the side closest to the pad per hole prototyping area (aka DOWN), the mouse is in HID mode. When plugged into a micro USB cable, the mouse will read the sensors (wheel, buttons, optical sensor), and function just like a mouse attached to your computer!

## Not-HID Mode
When the slide switch is on the side closest to the 7 pin female header (aka UP), the mouse is in the Not-HID mode. When plugged into a micro USB cable, the mouse will read the sensors (wheel, buttons, optical sensor) and send the data it gets over serial at 115200 baud. You can open any serial terminal to view the data from the mouse.

## Troubleshooting
The mice were packaged with the HID select switch in the HID position. If you plug your mouse in to a computer and it doesn't work like a mouse should, then check to make sure that the HID switch is in HID mode. The small tact switch labeled `SW1` is the reset button for the Leonardo. You can switch modes on the fly, and press this reset button to change modes without unplugging your mouse. If all else fails, re-program the mouse with the OpenMouse.ino code from the example in the Mousey Library.

# OLD HARDWARE INSTRUCTIONS
This section is for folks who have the old hardware, and is a guide for assembly. 

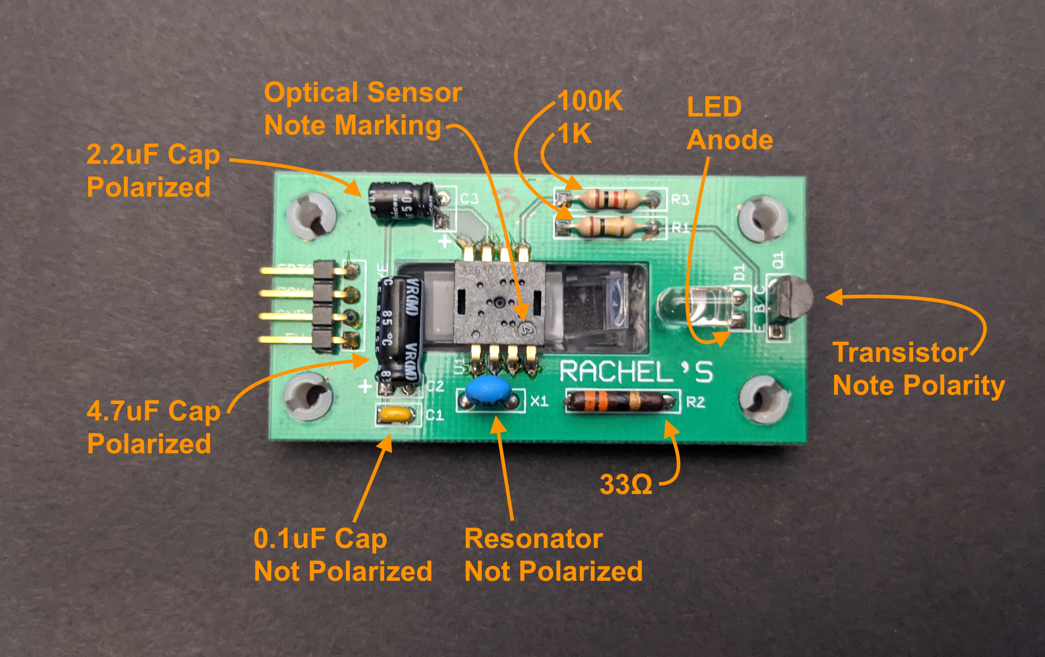
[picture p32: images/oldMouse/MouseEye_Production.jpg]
Mouse_Eye


This was made years ago, and I do have a small pile of parts and PCBs, if anyone is interested, drop me a message in the issues tab.

The image above is of the assembled board, showing where all the parts go. Below are all the parts, with the PCB reference numbers for your reference.

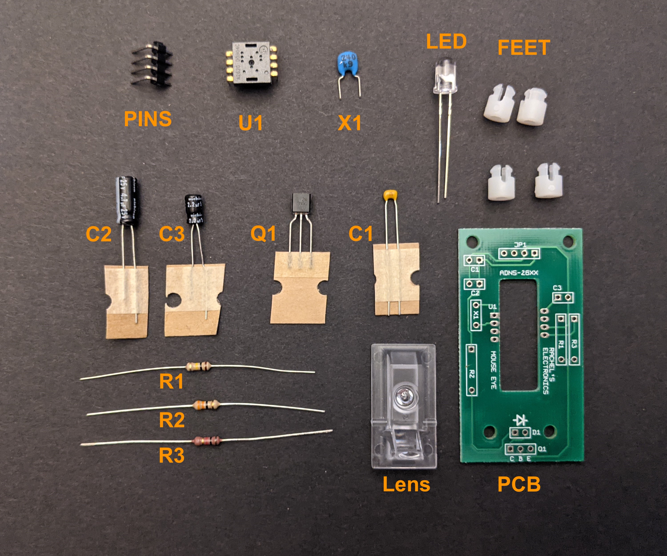
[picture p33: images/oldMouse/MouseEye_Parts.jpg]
Mouse_Eye_Parts


This is a beginner soldering project with a trap! You ***MUST*** and that is a big must, follow the same instructions for soldering the Optical Sensor as shown above in the main instructions. That is, you must place the PCB on a flat, heat resistant surface, Then put the Optical Sensor into position so that it's legs are touching the same surface as the PCB through the solder holes. Then, solder the legs from the top of the board. This will position the Optical Sensor *exactly* at the right height. The only other thing to think about is the LED will need to be bent over at a right angle to shine in the lens, so make sure there is enough lead for the bend when you solder.
Also, **DON'T USE CYANOACRYLATE TO GLUE THE LENS** Use regular old hot glue, or use something else but make sure no glue gets on the business part of the lens. Bad, very bad. 

## Old Mouse Firmware
This old project has less going on than the main project above. To make this work, please use the MouseEye library contained in the folder called MouseEye in this repository. It should work. Any issues, put them into the issue hole.

Have Fun!

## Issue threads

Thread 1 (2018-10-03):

Insertion of cradle can break the wheel axel

mwelling, 2018-10-03:
Should add a caution when inserting the cradle as it can break the wheel from the axel if not inserted carefully.

Sad to get that far just to snap the axel off into the encoder.

biomurph, 2018-10-03:
Oh No!
I will add that note to the instructions.
Please contact me biomurph at gmail to work out a replacement for that.

biomurph, 2018-10-04:
@mwelling I have extra wheel cradles and can ship you of you can't print your own

mwelling, 2018-10-04:
I am okay, somehow I ended up with two mice. Thanks for the offer though.

biomurph, 2018-10-04:
Two mice! You lucky bugger!

Closed 2018-10-04.

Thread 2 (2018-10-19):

bool

hydronics2, 2018-10-19:
hey! found an error

Mousey.h:70:3: error: 'boolen' does not name a type

   boolen buttonChange = false;

biomurph, 2018-10-19:
Awesome! Thanks @hydronics2 for your help!

Closed 2018-10-19.

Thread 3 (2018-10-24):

HID select switch (SW4) footprint

vektorious, 2018-10-24:
I am trying to source all the parts on DigiKey and apparently the HID select switch (SW4) is the only thing which I can't find and I where I am not sure about an equivalent replacement.

It's supposed to be the slider switch [SSSS810701 from Alps](https://www.alps.com/prod/info/E/HTML/Switch/Slide/SSSS8/SSSS810701.html) and I was looking at the footprint of the kicad_pcb file to get a similar ON-ON switch but I got a bit confused (probably a case of newbie confusion). The footprint has seven pads but as far as I can see the Alps switch has only 3 pins. Is the footprint actually universal for 3 and 4 pin switches Unfortunately I can't open the kicad.pro file because something with the libraries goes wrong but the connections in the .kicad_pcb file suggest that. That's why I chose [this 4 pin switch](https://www.digikey.de/product-detail/de/PCM12SMTR/401-2016-1-ND/1640125/?itemSeq=275199190) as a replacement.

I am sorry if this is totally obvious but are my assumptions correct?

Thank you in advance!
Alex

biomurph, 2018-10-24:
@vektorious Thanks for bringing the issue up.
The slider switch can be found on Mouser
https://www.mouser.com/ProductDetail/ALPS/SSSS810701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
if that link doesn't work, please try to do a search for the part SSSS810701.
You can also check Octopart for other suppliers.

Regarding the kicad files not working, that is another issue... I see the problem, and I will get it fixed asap.

biomurph, 2018-10-25:
That warning is OK to ignore. The schematic doesn't use the ADS1291/2 so you're g to g.
Glad that the digikey part fits! If you add the part number as an alternative to the BOM, and then send a pull request, we can track your contribution to the Mouse!

vektorious, 2018-12-07:
Just a quick update. I finally got all the parts from digikey and [the switch I got](https://www.digikey.de/product-detail/de/PCM12SMTR/401-2016-1-ND/1640125/?itemSeq=275199190) perfectly fits the footprint. I will add the part number (401-2016-1-ND)  to the BOM when I was able to fully rebuild the mouse an it actually works!

Closed 2018-10-25.

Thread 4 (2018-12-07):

Flash bootloader

vektorious, 2018-12-07:
I'm rebuilding the mouse basically from scratch and was wondering how I can flash the bootloader on the Arduino myself (I'm still learning). I found this [this guide](https://electronut.in/bootloader-atmega32u4/) and wanted to be sure if I can follow it and use the microUSB connection to get the bootloader on the chip.

Thanks in advance!

biomurph, 2018-12-10:
@vektorious you will need to install the bootloader before you can use the USB port to communicate with the ATmega32u4. For that, you will have to connect to the ICSP (In Circuit Serial Programming) pads. Those are the six SMT pads on the top of the board just above the PPH prototyping area.
Double check the schematic and PCB layout to make sure you get the connections right. Here's a tutorial on how to upload the bootloader
https://learn.sparkfun.com/tutorials/installing-an-arduino-bootloader/all
When I did this, I use the Arduino IDE to flash the 'Arduino Leonardo' bootloader to the mouse. Once that's done, you can program the mouse just like a Leonardo.

Closed 2019-06-17.

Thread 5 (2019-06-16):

Patents, other Questions

tderflinger, 2019-06-16:
Hi!
First of all, thanks for this great super mouse! I have a few questions:
- Is this design patent free?
- Can I buy an assembled mouse from you, or do I need to find an assembly company to do that for me?
- Do you have designs for the shell?

Thanks again for this cool idea!

biomurph, 2019-06-17:
@tderflinger
Hey, thanks for your interest in my Open Source Mouse! Here are your answers.

* There is not a patent on this design. It is Open Source. Please see the [OSHWA](www.oshwa.org) website for how to make sure that you are playing well with others. Basically, if you make anything from it, or make it and publish anything, you must attribute to me the work.

* This project was a gift in the shwag bag for the 2018 Open Source Hardware Summit. There are no more populated boards left. Also, the Mouse Eye Sensors and lenses are not available. I have some in my lab that I could sell you at cost plus a tiny amount. If you're interested, please let me know. All the other parts are available.

* I don't have any designs for the shell. That's on you.

You're welcome! I'm happy to sell you the EOL parts (Sensor and Lens) at a very good rate. LMK if you're interested. All the other parts are easy to solder by hand of with a stencil, paste, and reflow-gun.

tderflinger, 2019-06-19:
Hi BioMurph!

Thanks for offering to sell the EOL parts. When there is a need I will gladly come back to you.

I am relatively new to hardware and would like to give the design to a third party company to produce one piece for me.
Already, I have installed KiCad and looked at the PCB. Somehow I could not find the BOM with all the parts needed. Do you have a file with the parts numbers need to produce the mouse?

Regards,
-Tommy

biomurph, 2019-06-19:
The build is not too hard, but I understand that without experience it can be daunting.
I use [BetaLayout](https://us.beta-layout.com/pcb/) for prototypes. They give a free stencil, which makes assembly easy. Maybe there is a hacker space in your area that can assist?

The BOM is in the repo, in the `plots` file.

tderflinger, 2019-06-21:
All right, thanks for this information! I will check out BetaLayout.

Closed 2019-06-17.

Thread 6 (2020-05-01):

typo in image

millette, 2020-05-01:
Text (and repo) mentions ADNS2026 but the image https://github.com/biomurph/Mouse/blob/master/images/mouseAnatomy.png says "ADNS2016".

fireattack, 2020-05-01:
And the SparkFun link is a breakout for "ADNS2620".

biomurph, 2020-05-01:
Thanks! Nice to see some interest in the Mouse project!
Did you folks get one at the Summit a couple years ago?
Just getting to it in the COVID time of digging through old schwag bags?

fireattack, 2020-05-01:
> Thanks! Nice to see some interest in the Mouse project!
> Did you folks get one at the Summit a couple years ago?
> Just getting to it in the COVID time of digging through old schwag bags?

Someone posted it to Hacker News: https://news.ycombinator.com/item?id=23041747

You probably want to drop some insights there too!

Closed 2020-05-01.

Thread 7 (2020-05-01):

LOOKING FOR ADNS2620 ??

biomurph, 2020-05-01:
If you are looking for a Mouse Kit I have a small stash of ADS2620 in my lab. Please comment on this issue thread to learn more about how to get a kit or a sensor!

axiomdata, 2020-05-01:
I would be interested in getting a full kit.

calegxm999, 2020-07-30:
https://www.ebay.com.au/itm/1Pcs-ADNS-2620-A2620-DIP8-integrated-circuit/184068274587

calegxm999, 2020-07-30:
Where can I get a kit?

biomurph, 2020-07-30:
You will need a bit more than just the ADNS2620 sensor. It also requires a plastic lens, and an LED with the correct frequency output.

I don't have any complete kits, but I do have the LED, ADNS sensor, Lens, Resonator, and a few other parts necessary.
You would have to get your own PCB printed and assembled. It's not too hard a build, so even for a first timer, it's doable.

Realizing now that I didn't put up a BOM... I'll have to get to that shortly.

If you're seriously interested in getting the parts from me, reply to this thread and we can continue the conversation.

briancolgan, 2020-09-15:
Seen as though the ADNS-2620 went EOL years ago, the project may need to migrate to a newer Pixart sensor?

Pixart have two mouse sensors in 8-pin DIP that can be used with red LEDs, PAW3220DB-TJDR and PAW3212DB-TJDT.

They look like like good alternatives to the ADNS-2620?

biomurph, 2020-09-15:
@briancolgan
Yep, Pixart is the place the picked up the Avago mouse sensor parts.
Are you a sales rep for Pixart??
I have been in touch with them, but they are more miss than hit when it comes to follow up with me. I think my project is pretty small.

And, thanks for the reminder, I will get back to them on the thread that I have going.

briancolgan, 2020-09-15:
@biomurph Hi Joel, I work at EPS Global, we are Pixart's distributor in Europe.

For low volume projects below the Pixart MOQ, you can still buy their Sample Kits (Contents: 5 sets of Sensor + Lens + LED + Clip).

The **PAK3220RS-TJDR** is the sample kit for the PAW3220DB-TJDR sensor.
The **PAK3212RS-TJDT** is the sample kit for the PAW3212DB-TJDT sensor.

Hope that helps!

biomurph, 2020-09-15:
@briancolgan
Yes, that does help!
Can you connect me to Pixart's distribution in the US? I have been in contact with Open Source Hardware distributors and I want to sell this design as a kit. In order to get the to talk with me I need to have the BOM and supply chain worked out.

Thanks for reaching out and finding me! How did you get here, even?

briancolgan, 2020-09-15:
Pixart's distributor in US is WPG Americas http://www.wpgamericas.com/.

I found this project via EEVblog here: https://www.eevblog.com/forum/blog/eevblog-1244-mailbag/msg2677794/

I was reminded of it when I saw this thread on the ADNS-2620.
https://www.eevblog.com/forum/projects/source-for-an-optical-mouse-sensor-like-the-adns2620/msg3110516/

biomurph, 2020-09-15:
Oh, Great! Glad to hear that the EEV Blog is getting folks over to me ;)
I just replied on a thread from last year, and a rep from WPG got back to me within 10 minues.
I'll see how it goes. Thanks again!

justinclift, 2020-09-15:
Interesting.  Hadn't come across the "Mailbag" segment on EEVblog before.  Looks useful for aspiring projects trying to get noticed. :smile:

justinclift, 2020-09-15:
> Glad to hear that the EEV Blog is getting folks over to me

They're covering the Tympan in the same episode too:

&nbsp; &nbsp; https://youtu.be/Uib8nUV1JEg?t=202

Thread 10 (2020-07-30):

Can you use the mouse on other computers without installing Arduino Software?

calegxm999, 2020-07-30:
Can I use this on a friends laptop, without installing anything on their laptop?

biomurph, 2020-07-30:
@calegxm999
Short answer: Yes!
The  mouse is basically an Arduino Leonardo that when programmed with the software in this repo, will appear as a HID mouse when you plug it into USB on any computer (windows, mac, linux, etc).

Closed 2020-07-30.

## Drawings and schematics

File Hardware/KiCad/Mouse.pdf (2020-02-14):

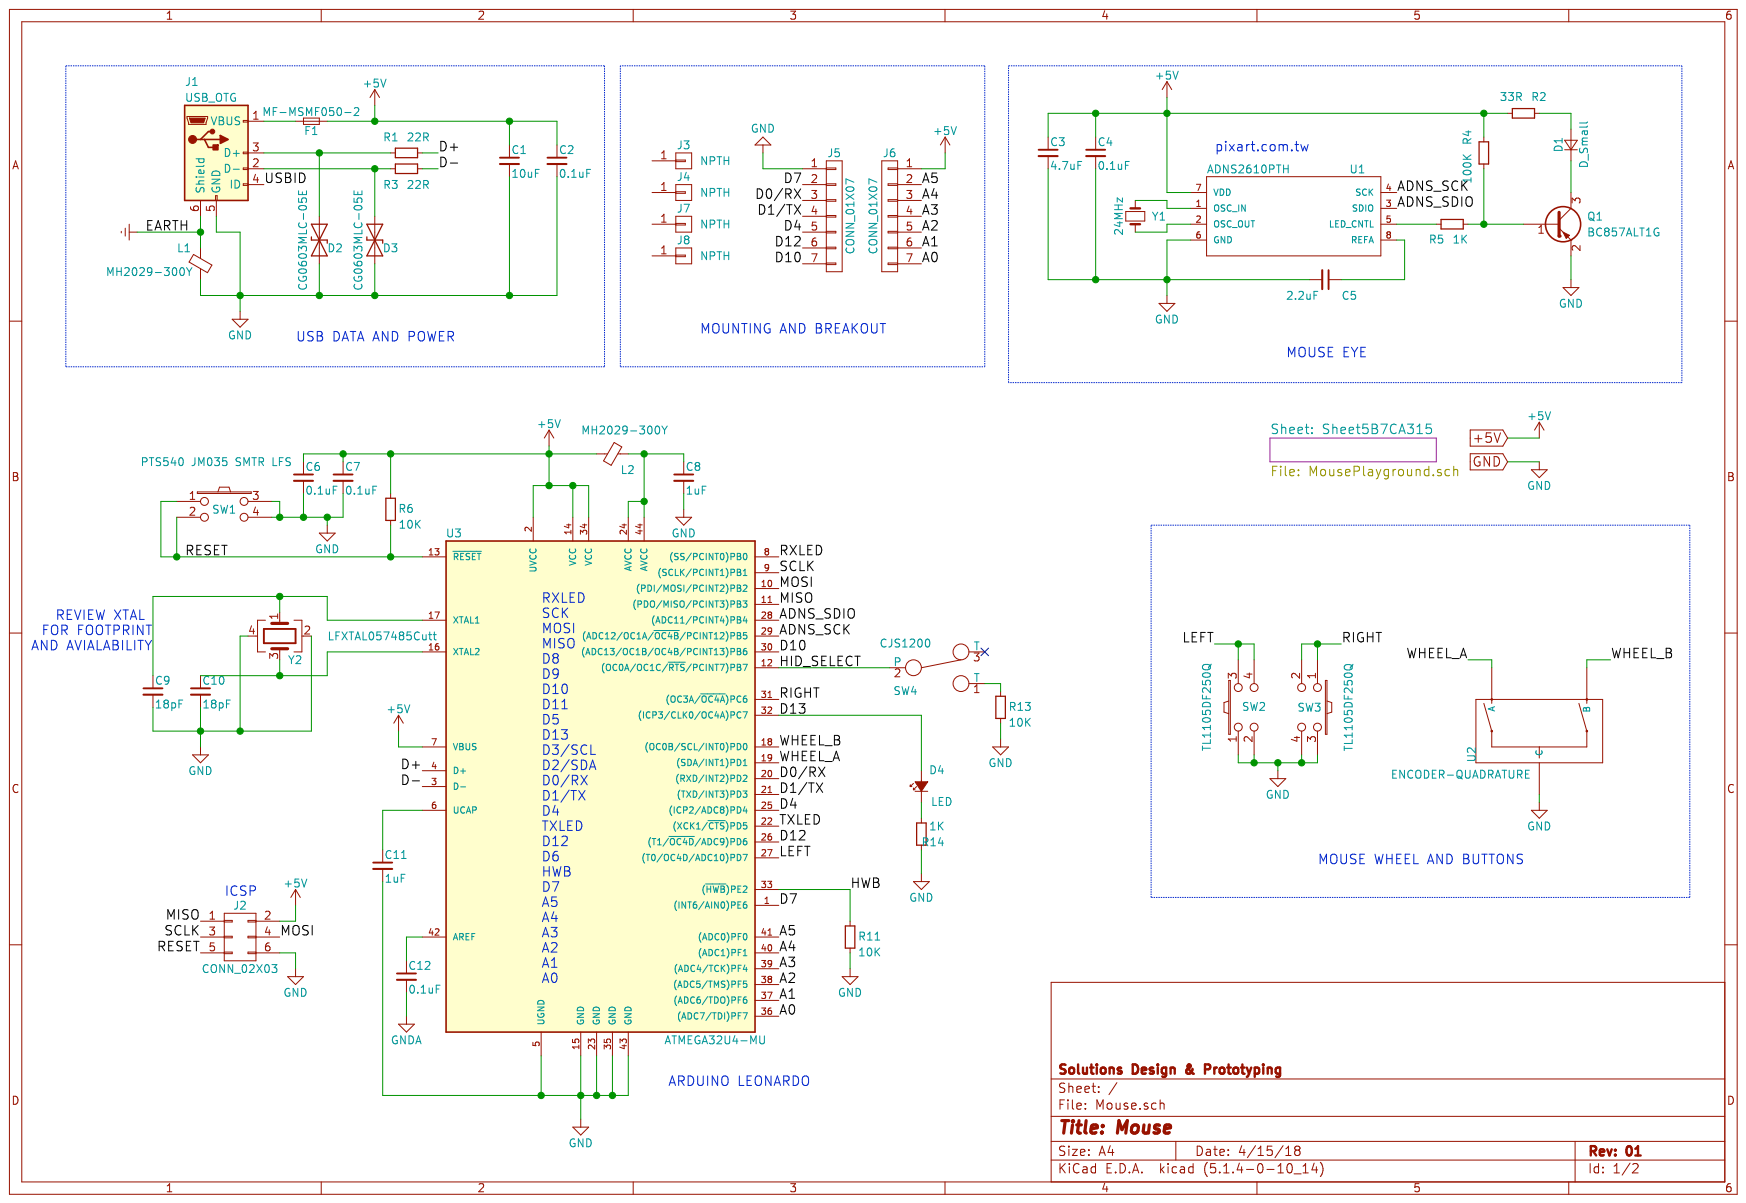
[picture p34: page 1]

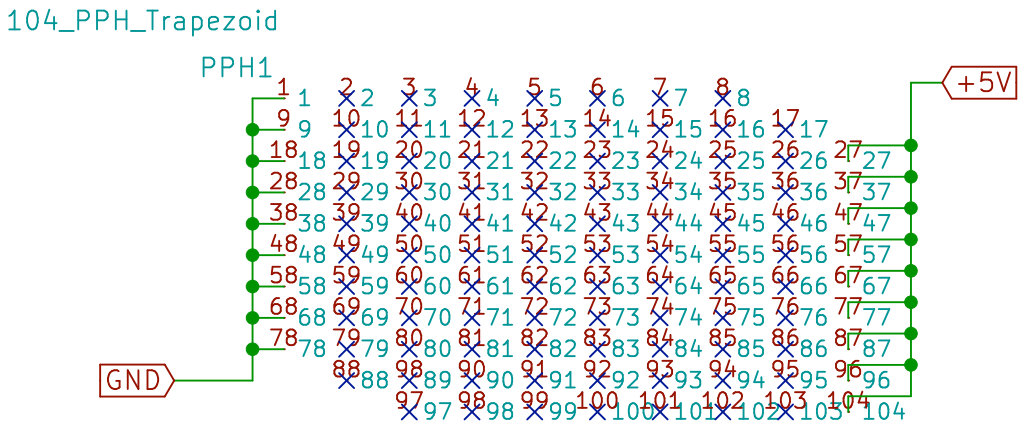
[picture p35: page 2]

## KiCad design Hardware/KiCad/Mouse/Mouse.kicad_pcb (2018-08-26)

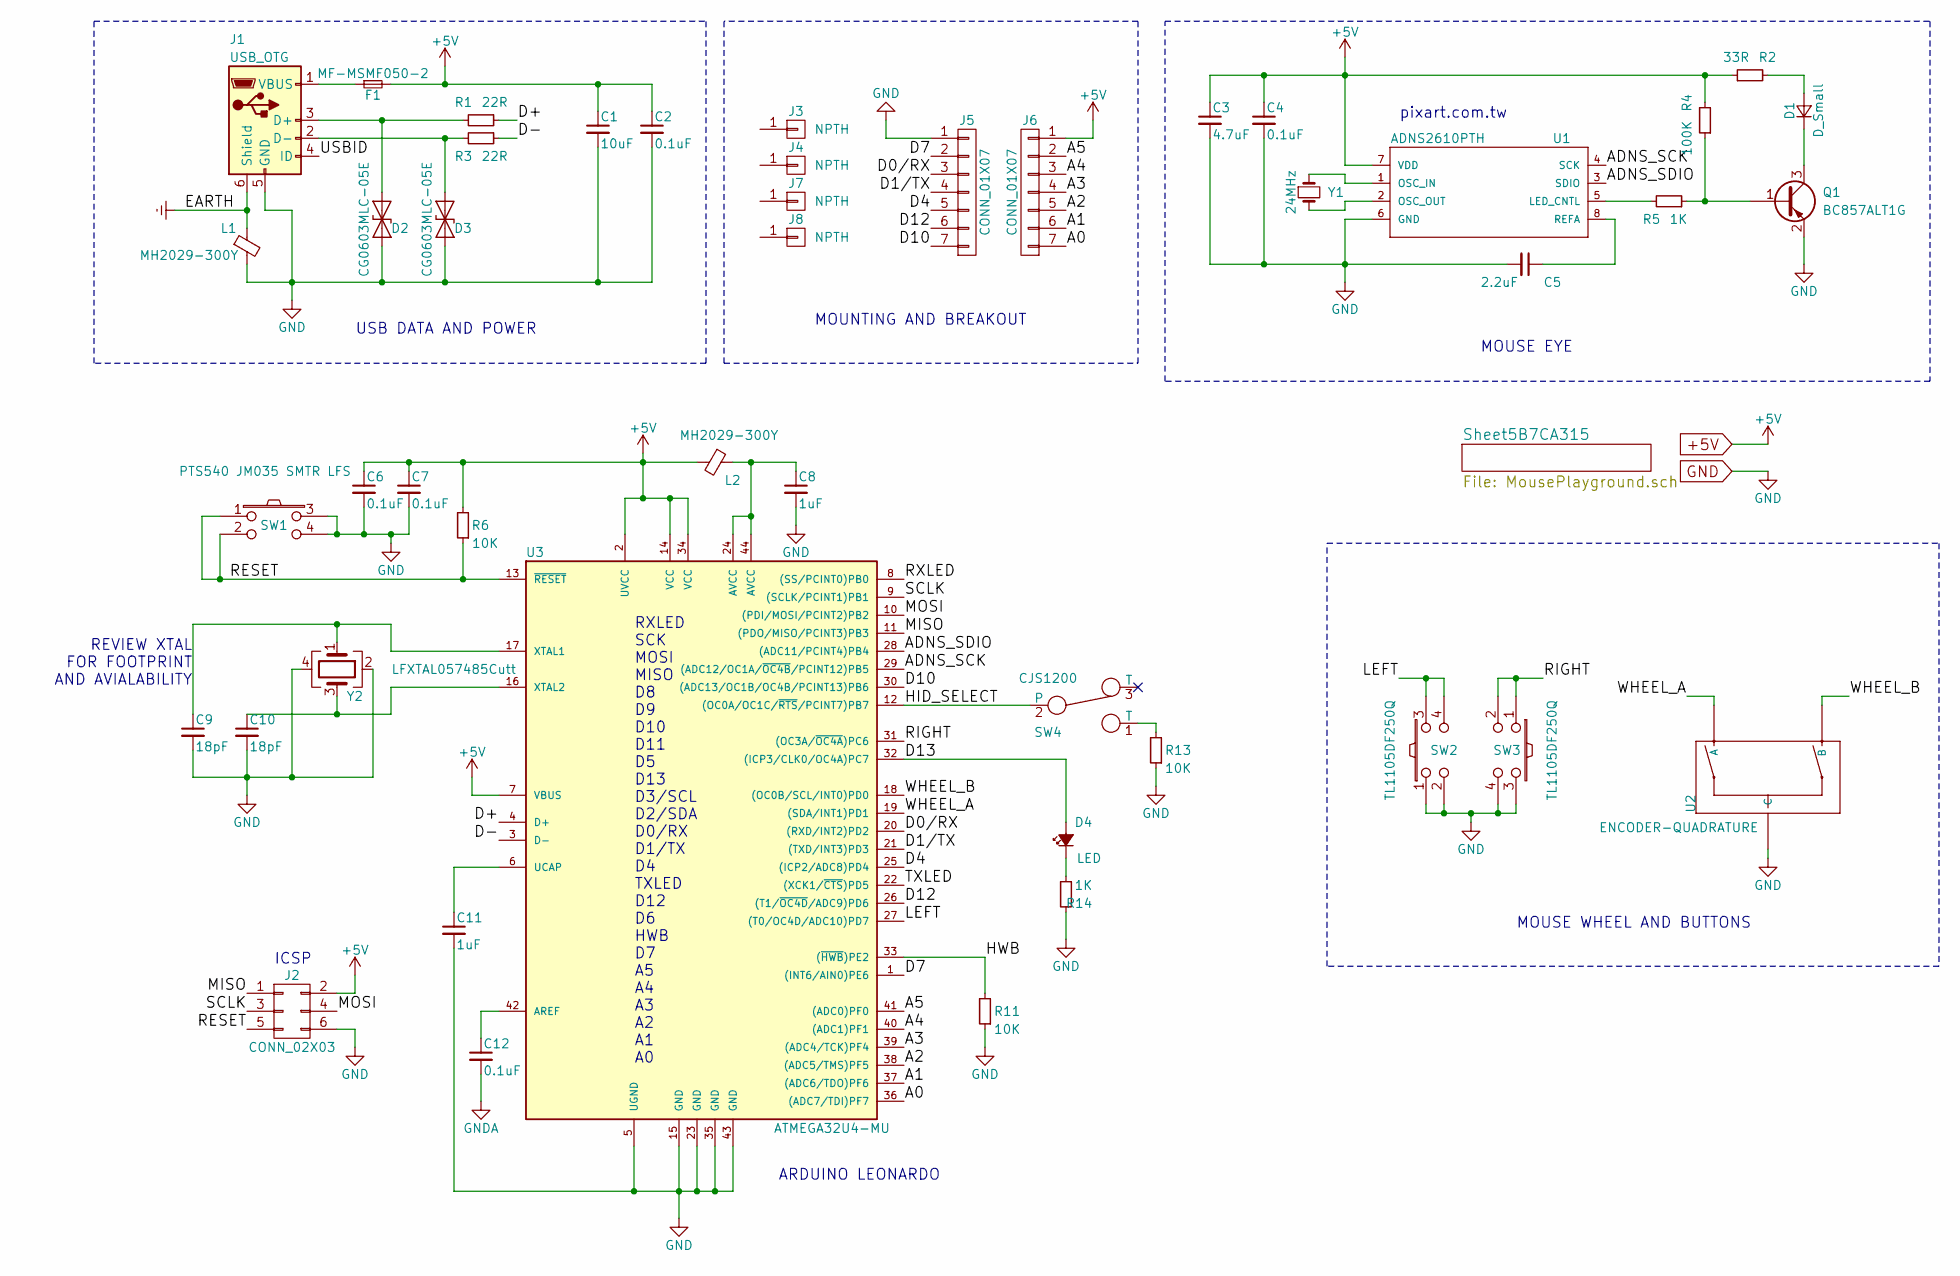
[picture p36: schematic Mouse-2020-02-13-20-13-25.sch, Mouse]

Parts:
C1: 10uF; C_0603
C2, C4, C6, C7, C12: 0.1uF; C_0603
C3: 4.7uF; C_0603
C5: 2.2uF; C_0603
C8, C11: 1uF; C_0603
C9, C10: 18pF; C_0603
D1: D_Small; LED_D5.0mm_Horizontal_O1.27mm_Z3.0mm
D2, D3: CG0603MLC-05E; C_0603
D4: LED; C_0603
F1: MF-MSMF050-2; C_1812
J1: USB_OTG; 10118193_microUSB
J2: CONN_02X03; Pin_Header_Straight_2x03_Pitch2.54mm_SMD
J3, J4, J7, J8: NPTH; NPTH_1875
J5, J6: CONN_01X07; Pin_Header_Straight_1x07_Pitch2.54mm
L1, L2: MH2029-300Y; C_0805
Q1: BC857ALT1G; SOT-23
R1, R3: 22R; C_0603
R2: 33R; C_0603
R4: 100K; C_0603
R5, R14: 1K; C_0603
R6, R11, R13: 10K; C_0603
SW1: PTS540 JM035 SMTR LFS; PTS540_Switch
SW2, SW3: TL1105DF250Q; Mouse_Button
SW4: CJS1200; SSSS810701_ALPS_DPDT
U1: ADNS2610PTH; ADNS2610
U2: ENCODER-QUADRATURE; Mouse_Encoder
U3: ATMEGA32U4-MU; LQFP-44_10x10mm_Pitch0.8mm
Y1: 24MHz; C_Disc_D5.0mm_W2.5mm_P5.00mm
Y2: LFXTAL057485Cutt; Crystal_SMD_3225-4pin_3.2x2.5mm

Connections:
+5V: C1.1, C2.1, C3.1, C4.1, C6.1, C7.1, F1.2, J2.2, J6.1, L2.2, R2.1, R4.2, R6.2, U1.7 (VDD), U3.2 (UVCC), U3.7 (VBUS), U3.14 (VCC), U3.34 (VCC); also elsewhere on the board
/A0: J6.7, U3.36 ((ADC7/TDI)PF7)
/A1: J6.6, U3.37 ((ADC6/TDO)PF6)
/A2: J6.5, U3.38 ((ADC5/TMS)PF5)
/A3: J6.4, U3.39 ((ADC4/TCK)PF4)
/A4: J6.3, U3.40 ((ADC1)PF1)
/A5: J6.2, U3.41 ((ADC0)PF0)
/ADNS_SCK: U1.4 (SCK), U3.29 ((ADC12/OC1A/~OC4B~/PCINT12)PB5)
/ADNS_SDIO: U1.3 (SDIO), U3.28 ((ADC11/PCINT4)PB4)
/D0/RX: J5.3, U3.20 ((RXD/INT2)PD2)
/D1/TX: J5.4, U3.21 ((TXD/INT3)PD3)
/D4: J5.5, U3.25 ((ICP2/ADC8)PD4)
/D7: J5.2, U3.1 ((INT6/AIN0)PE6)
/D10: J5.7, U3.30 ((ADC13/OC1B/OC4B/PCINT13)PB6)
/D12: J5.6, U3.26 ((T1/~OC4D~/ADC9)PD6)
/D13: D4.2 (A), U3.32 ((ICP3/CLK0/OC4A)PC7)
/D+: R1.1, U3.4 (D+)
/D-: R3.1, U3.3 (D-)
/HID_SELECT: SW4.2, U3.12 ((OC0A/OC1C/~RTS~/PCINT7)PB7)
/HWB: R11.2, U3.33 ((~HWB~)PE2)
/LEFT: SW2.3, SW2.4, U3.27 ((T0/OC4D/ADC10)PD7)
/MISO: J2.1, U3.11 ((PDO/MISO/PCINT3)PB3)
/MOSI: J2.4, U3.10 ((PDI/MOSI/PCINT2)PB2)
/RESET: J2.5, R6.1, SW1.1, SW1.2, U3.13 (~RESET~)
/RIGHT: SW3.1, SW3.2, U3.31 ((OC3A/~OC4A~)PC6)
/RXLED: U3.8 ((SS/PCINT0)PB0)
/SCLK: J2.3, U3.9 ((SCLK/PCINT1)PB1)
/TXLED: U3.22 ((XCK1/~CTS~)PD5)
/USBID: J1.4 (ID)
/WHEEL_A: U2.A, U3.19 ((SDA/INT1)PD1)
/WHEEL_B: U2.B, U3.18 ((OC0B/SCL/INT0)PD0)
Earth: J1.6 (Shield), J1.7, J1.8, J1.9, J1.10, J1.11, L1.1
GND: C1.2, C2.2, C3.2, C4.2, C5.2, C6.2, C7.2, C8.2, C9.2, C10.2, C11.2, D2.2 (A2), D3.2 (A2), J1.5 (GND), J2.6, J5.1, L1.2, Q1.2 (E), R11.1, R13.1, R14.2, SW1.3, SW1.4, SW2.1, SW2.2, SW3.3, SW3.4, U1.6 (GND), U2.4, U2.5, U2.C, U3.5 (UGND), U3.15 (GND), U3.23 (GND), U3.35 (GND), U3.43 (GND), Y2.2, Y2.4; also elsewhere on the board
GNDA: C12.2
unnamed: C5.1, U1.8 (REFA)
unnamed: C8.1, L2.1, U3.24 (AVCC), U3.44 (AVCC)
unnamed: C9.1, U3.17 (XTAL1), Y2.1
unnamed: C10.1, U3.16 (XTAL2), Y2.3
unnamed: C11.1, U3.6 (UCAP)
unnamed: C12.1, U3.42 (AREF)
unnamed: D1.1 (K), Q1.3 (C)
unnamed: D1.2 (A), R2.2
unnamed: D2.1 (A1), J1.3 (D+), R1.2
unnamed: D3.1 (A1), J1.2 (D-), R3.2
unnamed: D4.1 (K), R14.1
unnamed: F1.1, J1.1 (VBUS)
unnamed: Q1.1 (B), R4.1, R5.1
unnamed: R5.2, U1.5 (LED_CNTL)
unnamed: R13.2, SW4.1 (T)
unnamed: U1.1 (OSC_IN), Y1.1
unnamed: U1.2 (OSC_OUT), Y1.2

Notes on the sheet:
ICSP
pixart.com.tw
MOUSE WHEEL AND BUTTONS
MOUSE EYE
USB DATA AND POWER
ARDUINO LEONARDO
MOUNTING AND BREAKOUT
RXLED SCK MOSI MISO D8 D9 D10 D11 D5 D13 D3/SCL D2/SDA D0/RX D1/TX D4 TXLED D12 D6 HWB D7 A5 A4 A3 A2 A1 A0
REVIEW XTAL FOR FOOTPRINT AND AVIALABILITY

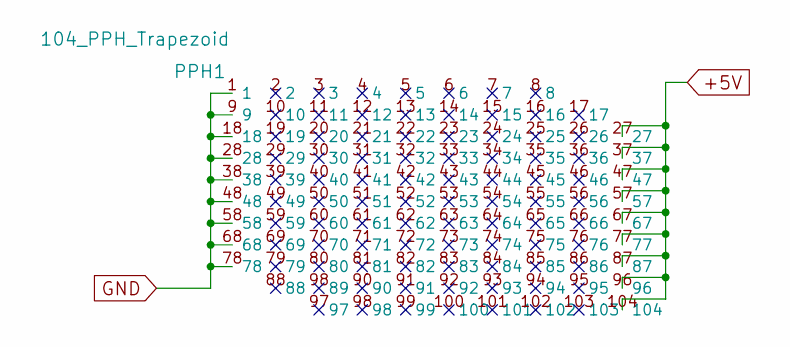
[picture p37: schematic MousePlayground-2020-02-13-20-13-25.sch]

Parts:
PPH1: 104_PPH_Trapezoid; Mouse_PPH_Array

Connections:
+5V: PPH1.27, PPH1.37, PPH1.47, PPH1.57, PPH1.67, PPH1.77, PPH1.87, PPH1.96, PPH1.104; also elsewhere on the board
GND: PPH1.1, PPH1.9, PPH1.18, PPH1.28, PPH1.38, PPH1.48, PPH1.58, PPH1.68, PPH1.78; also elsewhere on the board

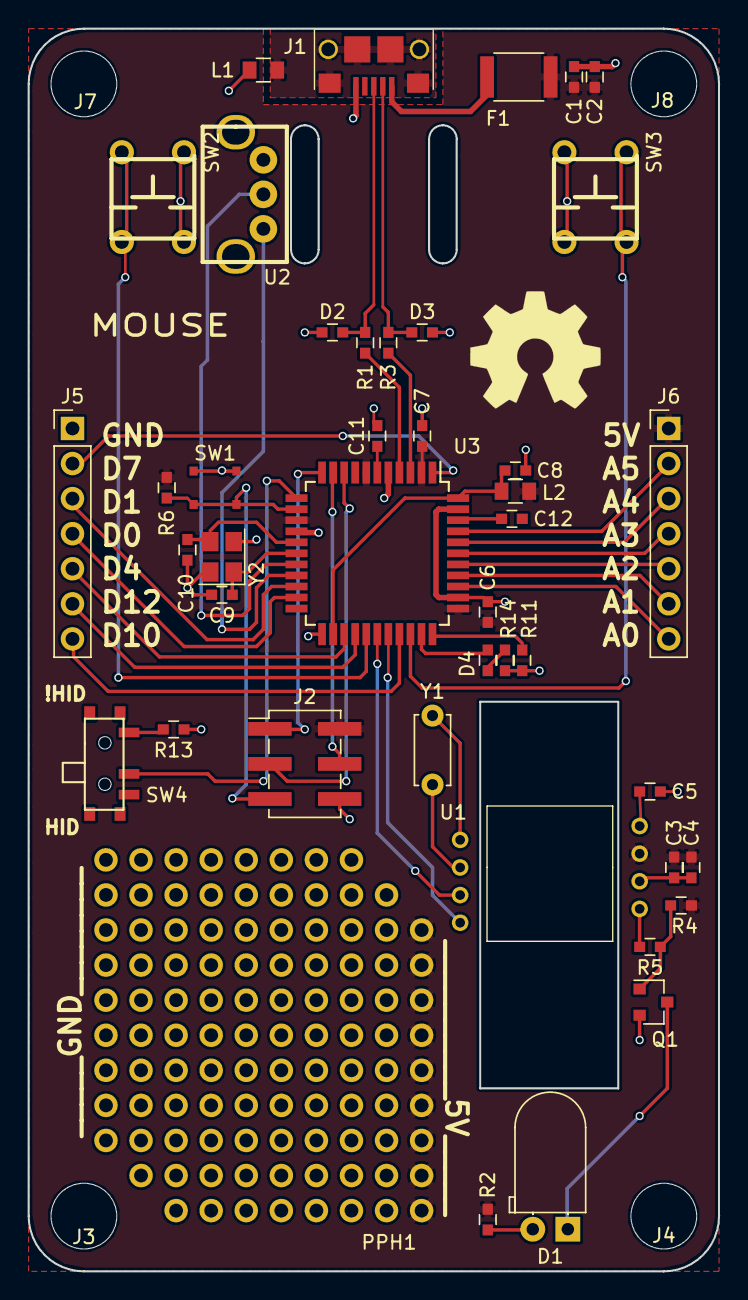
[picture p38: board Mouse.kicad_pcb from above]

Board: 2 copper layers, 50.0 x 90.0 mm, 47 parts (0 on the bottom side), 47 nets.

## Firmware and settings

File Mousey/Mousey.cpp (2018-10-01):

/*


*/




#include "Mousey.h"

Mousey::Mousey(){
	setPins();	// initialize pins DO THIS FIRST!
}

boolean Mousey::start()
{
	delay(1000);	// necessary for ADNS!

  hid = digitalRead(HID_SELECT);	// check if we are in HID mode
  if(hid){
    Mouse.begin();
  } else {
    Serial.begin(115200);
		delay(1000);
    Serial.println("not running as HID");
    Serial.println("Mousey Library");
  }
	return true;
}

/*
	CHECKS FOR AND UPDATES BUTTONS, WHEEL, X-Y MOVEMENT
*/
void Mousey::update(){
	checkEye();			// checks for mouse movement and sets updateMouse
  checkWheel();		// checks for wheel movement and sets updateMouse
  checkButtons(); // sends pressed and released on button events
  if(updateMouse){
    updateMouse = false;
		if(hid){
	    Mouse.move(deltaX, deltaY, wheelDelta);
		}else{	// if !hid send the data to serial terminal
			Serial.print("x ");Serial.print(deltaX,DEC);Serial.print('\t');
		  Serial.print("y ");Serial.print(deltaY,DEC);Serial.print('\t');
		  Serial.print("w ");Serial.print(wheelDelta);Serial.print('\n');
		}
		wheelDelta = 0;	// reset wheelDelta so we don't keep scrolling!
  }

  if(!hid){ eventSerial(); }	// option to talk to mouse
}

/*
	WHEN MOUSE EYE SEES MOVEMENT updateMouse IS SET
*/

void Mousey::checkEye() {
  getMouseEyeDelta();      // update deltaX and deltaY variables
  if (deltaX != 0 || deltaY != 0) { //when mouse is moving
      updateMouse = true;	// updateMouse can be set here or by checkWheel
  }
}

/*
	POLLS THE wheelMove BOOLEAN, WHICH IS SET IN encode()

*/
void Mousey::checkWheel(){
  if(wheelMoved){
		wheelMoved = false;
    updateMouse = true;	// updateMouse can be set here or by the checkEye
  }
}

/*
	CHECKS BUTTON STATE USING A millis() TIMER
*/
void Mousey::checkButtons() {
  int button;
  for(int i=0; i<2; i++){
    button = digitalRead(buttonPin[i]);
    if (button != lastButtonState[i]) {
      lastBounce = millis();
      bounce = i+1; //
      lastButtonState[i] = button;
			buttonChange = true;
    }
  }
	if(buttonChange){
	  if((millis() - lastBounce) > bounceDelay) {
	    switch(bounce){
	      case 0:
	        break;
	      case 1:
	        sendButton(MOUSE_LEFT, lastButtonState[0]);
	        break;
	      case 2:
	        sendButton(MOUSE_RIGHT, lastButtonState[1]);
	        break;
	      default:
	        break;
	    }
			buttonChange = false;
	    bounce = 0;
	  }
	}
}

/*
	SENDS THE BUTTON STATE AS HID OR TO SERIAL TERMINAL
	BUTTONS USE INTERNAL PULLUPS
	HIGH IS RELEASE, LOW IS PRESS
	TODO reduce the serial print statements, make function more efficient
*/
void Mousey::sendButton(int activeButton, int state){
	if(!hid){ Serial.print("button "); Serial.print(activeButton); Serial.print(" = "); }
  if(state){	//
    if(hid){
      Mouse.release(activeButton);
    } else {
      Serial.println(state);
    }
  } else {
    if(hid){
      Mouse.press(activeButton);
    } else {
      Serial.println(state);
    }
  }
}

/*
	ENCODE IS CALLED FROM THE ISR IN THE .ino FILE
	TODO: MOVE THE attachInterrupt AND ISR INTO THE LIBRARY
*/
void Mousey::encode(){
  wheelState = 0x00;
  for(int i=0; i<2; i++){
    wheelState |= (digitalRead(wheel[i]) << i);
  }
  if(wheelState != lastWheelState){
    switch(wheelState){
      case 0x00:
          fwd = true;
        break;
      case 0x01:
          fwd = false;
        break;
      case 0x02:
        fwd = false;
        break;
      case 0x03:
        fwd = true;
        break;
      default:
        break;
    }
    if(fwd){	// Change the direction of the wheel if you like
      wheelPos ++;
			// wheelPos --;
    }else{
      wheelPos --;
			// wheelPos ++;
    }
    wheelDelta = wheelPos - lastWheelPos;
    lastWheelPos = wheelPos;
    lastWheelState = wheelState;
    wheelMoved = true;
    }
  }

/*
	THE FOLLOWING FUNCTIONS COMMUNICATE WITH THE ADNS2620
*/

void Mousey::getMouseEyeDelta()
{
	deltaY = readDNS(0x42);
	deltaX = readDNS(0x43);
	deltaY = ~deltaY; deltaY++;	// invert deltaY
	// deltaX = ~deltaX; deltaX++;	// invert deltaX
}


uint8_t Mousey::Config_Read()
{
	byte n = readDNS(0x40);
	return n;
}

void Mousey::Config_Write(byte cfig)
{
	writeDNS(0x40,cfig);
}

uint8_t Mousey::Status()
{
	byte n = readDNS(0x41);
	return n;
}

int Mousey::Squal()
{
	b = readDNS(0x44);
	return b*2;
}

uint8_t Mousey::Max_Pixel()
{
	b = readDNS(0x45);
	return b;
}

uint8_t Mousey::Min_Pixel()
{
	b = readDNS(0x46);
	return b;
}

int Mousey::Pixel_Sum()
{
	b = readDNS(0x47);
	int sum = b*128;
	return sum;
}

word Mousey::Shutter()
{
	word w;
	sUpper = readDNS(0x49);
	sLower = readDNS(0x4A);
	w = word(sUpper,sLower);
	return w;
}

short Mousey::Frame_Period_Read()
{
	b = readDNS(0x4B);
	short period = b << 8;
	return period;
}

void Mousey::Frame_Period_Write(short period)
{
	b = period >> 8;
	writeDNS(0x4B,b);
}

void Mousey::Pixel_Data()
{
	writeDNS(0x48,0x48);
}

byte Mousey::Pixel_Data_Read()
{
	b = readDNS(0x48);
	return b;
}

byte Mousey::readDNS(byte outByte){
  int i;
  byte inByte;
  for (i=7; i>=0; i--){        		//choose bit send
    digitalWrite(SCK,LOW);     		//setup on falling edge
    digitalWrite(SDIO, (bitRead(outByte,i)));	//send bit
    digitalWrite(SCK,HIGH);    		//DNS samples on rising edge
  }
  delayMicroseconds(20);		// wait for ADNS to get hold of data line
  pinMode(SDIO,INPUT);         		//get ready to read
  delayMicroseconds(80);
  for (i=7; i>=0; i--){        		//choose bit to store
    digitalWrite(SCK,LOW);     		//DNS sets up on falling edge
    digitalWrite(SCK,HIGH);    		//sample on rising edge
    bitWrite(inByte,i,(digitalRead(SDIO)));	//get bit
  }
  pinMode(SDIO, OUTPUT); digitalWrite(SDIO,HIGH);		//reset SDIO for next time
  return inByte;			//return byte
}// end readDNS



void Mousey::writeDNS(byte high, byte low){
  word outWord = word(high,low);  	//load bytes into the chute
  bitSet(outWord,15);               		//we want to write data
  for (int i=15; i>=0; i--){    		//choose bit MSB
    digitalWrite(SCK,LOW);      		//setup on falling edge
    digitalWrite(SDIO, (bitRead(outWord,i)));    	//send bit
    digitalWrite(SCK,HIGH);
  }
	digitalWrite(SDIO,HIGH);
}

/*
	SET PIN DIRECTIONS
*/
void Mousey::setPins()
{
	pinMode(LEFT, INPUT_PULLUP);
  pinMode(RIGHT, INPUT_PULLUP);
  pinMode(HID_SELECT, INPUT_PULLUP);
  pinMode(WHEEL_A, INPUT_PULLUP);
  pinMode(WHEEL_B, INPUT_PULLUP);
	pinMode(SDIO, OUTPUT); digitalWrite(SDIO,HIGH); // data idles high
  pinMode(SCK, OUTPUT); digitalWrite(SCK,HIGH);	//clock idles high
	for(int i=0; i<2; i++){
    pinMode(wheel[i],INPUT_PULLUP);
  }
  // attachInterrupt(digitalPinToInterrupt(WHEEL_A), encode, CHANGE);
}

/*
	OPPORTUNITY TO TALK TO THE MOUSE, IF YOU LIKE
*/

void Mousey::eventSerial(){
  char inChar;
  if(Serial.available()){
    inChar = Serial.read();
    switch(inChar){
      case 'h':
        hid = digitalRead(HID_SELECT);
        Serial.print("HID = "); Serial.println(hid);
        break;
      default:
        break;
    }
  }
};

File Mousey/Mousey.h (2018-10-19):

#ifndef Mousey_H
#define Mousey_H

#include <Arduino.h>
#include <stdint.h>
#include <Mouse.h>

// PINS
#define	SCK  9
#define SDIO 8
#define HID_SELECT  11
#define WHEEL_A 2
#define WHEEL_B 3
#define RIGHT 5
#define LEFT  6
#define LED 13

class Mousey {
public:
	  Mousey();
		boolean hid = false;
		boolean start(void);
		void setPins(void);
		void eventSerial(void);
		void update(void);
		void checkEye(void);
		void checkWheel(void);
		void checkButtons(void);
		void sendButton(int,int);
		void encode(void);
		void getMouseEyeDelta();
    uint8_t Config_Read();
    void Config_Write(uint8_t);
    uint8_t Status();
    int Squal();
    uint8_t Max_Pixel();
    uint8_t Min_Pixel();
    int Pixel_Sum();
    word Shutter();
    short Frame_Period_Read();
    void Frame_Period_Write(short);
    void Pixel_Data();
    byte Pixel_Data_Read();
		volatile boolean wheelMoved = false;
    char deltaX;
    char deltaY;


private:
		volatile byte wheelState = 0x00;     // holds the state of A and B
		volatile byte lastWheelState = 0x00; // remembers the last state of A and B
		//volatile int wheel[2] = {WHEEL_A, WHEEL_B};
		volatile boolean fwd = false;
		boolean lastDirection = false;
		//volatile boolean wheelMove = false;
		volatile unsigned long wheelPos = 0;
		volatile unsigned long lastWheelPos = 0;
		volatile int wheelDelta = 0;
		volatile int wheel[2] = {WHEEL_A, WHEEL_B};
		boolean updateMouse = false;
		int buttonPin[2] = {LEFT,RIGHT};
		int buttonState[2];             // the current reading from the mouse buttons
		int lastButtonState[2] = {LOW,LOW};   // the previous reading from the input pin
		long lastBounce = 0;            // the last time the output pin was toggled
		unsigned long bounceDelay = 10;          // the debounce time; increase if the output flickers
		int bounce = 0;
		boolean buttonChange = false;
    uint8_t b;
    uint8_t sUpper;
    uint8_t sLower;
    void writeDNS(byte, byte);	// write data to ADNS register
    uint8_t readDNS(uint8_t);		// read data from ADNS register
};

#endif

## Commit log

2018-08-08 Got the eye and buttons working
2018-08-08 First stab at wheel support STL
    [MouseWheelSupport (1).stl, MouseWheelSupport.stl]
2018-08-21 Added alternate mouse wheel support
    [MouseWheelSupport (1).stl, MouseWheelSupport.stl]
2018-08-22 added the new Mousey library and fixed bugs.
    [MouseEye.cpp, MouseEye_X_Y.ino, Mousey.cpp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]
2018-08-26 added design files
    [Mouse-B.Cu.gbr, Mouse-B.Mask.gbr, Mouse-B.Paste.gbr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]
2018-09-26 Added assembly instructions and updated readme
    [Mouse_BOM.xlsx]
2018-09-26 added board refs to instructions
2018-09-27 added pics to assembly instructions
2018-10-01 typos, edits, added STL for wheel parts
    [Assem6 - Mouse_Wheel.STL, Clip^Assem9.STL, MouseWheelSupport.stl]
2018-10-03 Added caution about inserting the wheel holder
2018-10-19 Fixed varialble instance bug
    [Mousey.h]
2018-10-24 Repaired parts library paths
    [Mouse-B.Cu.gbr, Mouse-B.Mask.gbr, Mouse-B.Paste.gbr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]
2020-02-14 ensuring this still works with KiCad
    [Mouse-2020-02-13-20-13-25.sch, MousePlayground-2020-02-13-20-13-25.sch]
2020-07-30 Added BOM !
    [Mouse_BOM.csv]
